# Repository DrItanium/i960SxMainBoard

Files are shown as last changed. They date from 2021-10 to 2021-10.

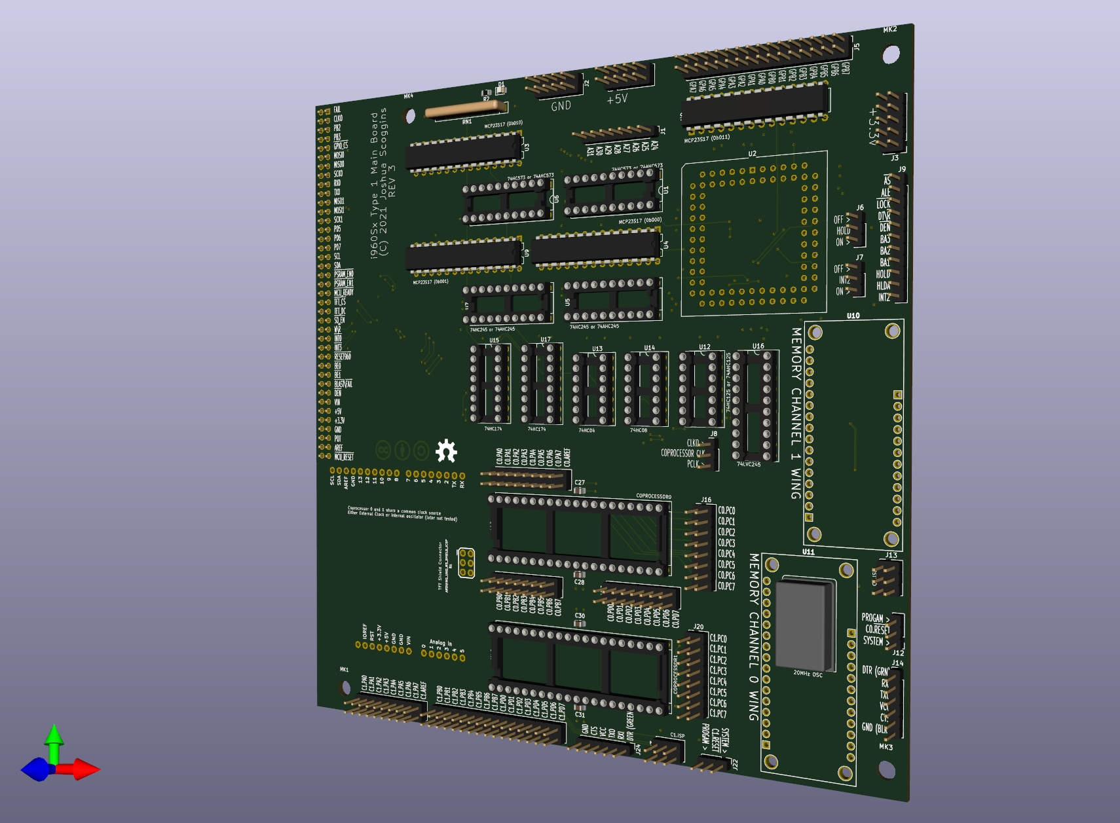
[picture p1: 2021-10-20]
images/i960BasicProcessorHardware_REV3_SIDE0.png

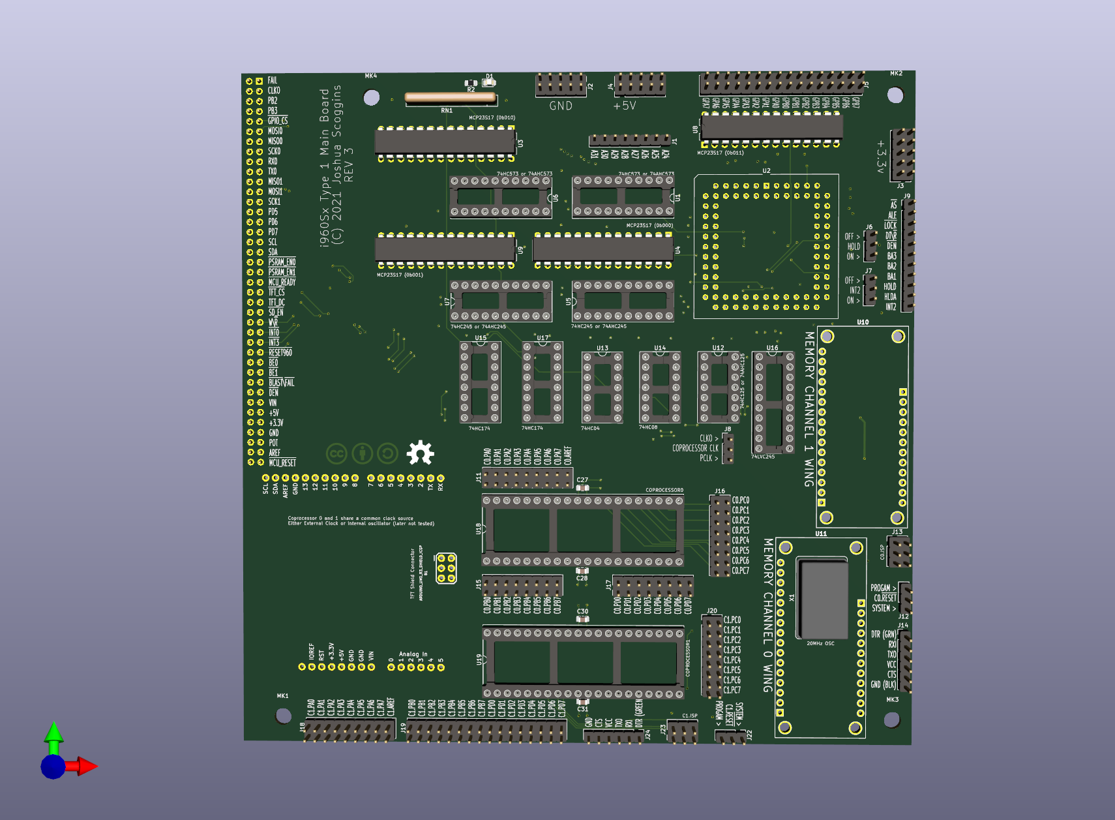
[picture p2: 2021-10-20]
images/i960BasicProcessorHardware_REV3_FRONT.png

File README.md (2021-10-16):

This is the kicad project for my basic i960Sx mainboard

This is the culmination of many different designs with the most prominent being
the flattening of my internal modular board design. It was made up of mega2560
shield form factors and nucleo-144 form factor boards. It allowed me to mix and
match ideas without having to fully lay everything out over and over again. I
have no plans of releasing those designs publically because they are not
useful to anyone but myself.

This is a mini-itx board that requires a separate MightyCore development board
to plug into. This board is the culmination of years of work and design. I am
nowhere done but this is the next phase of the design

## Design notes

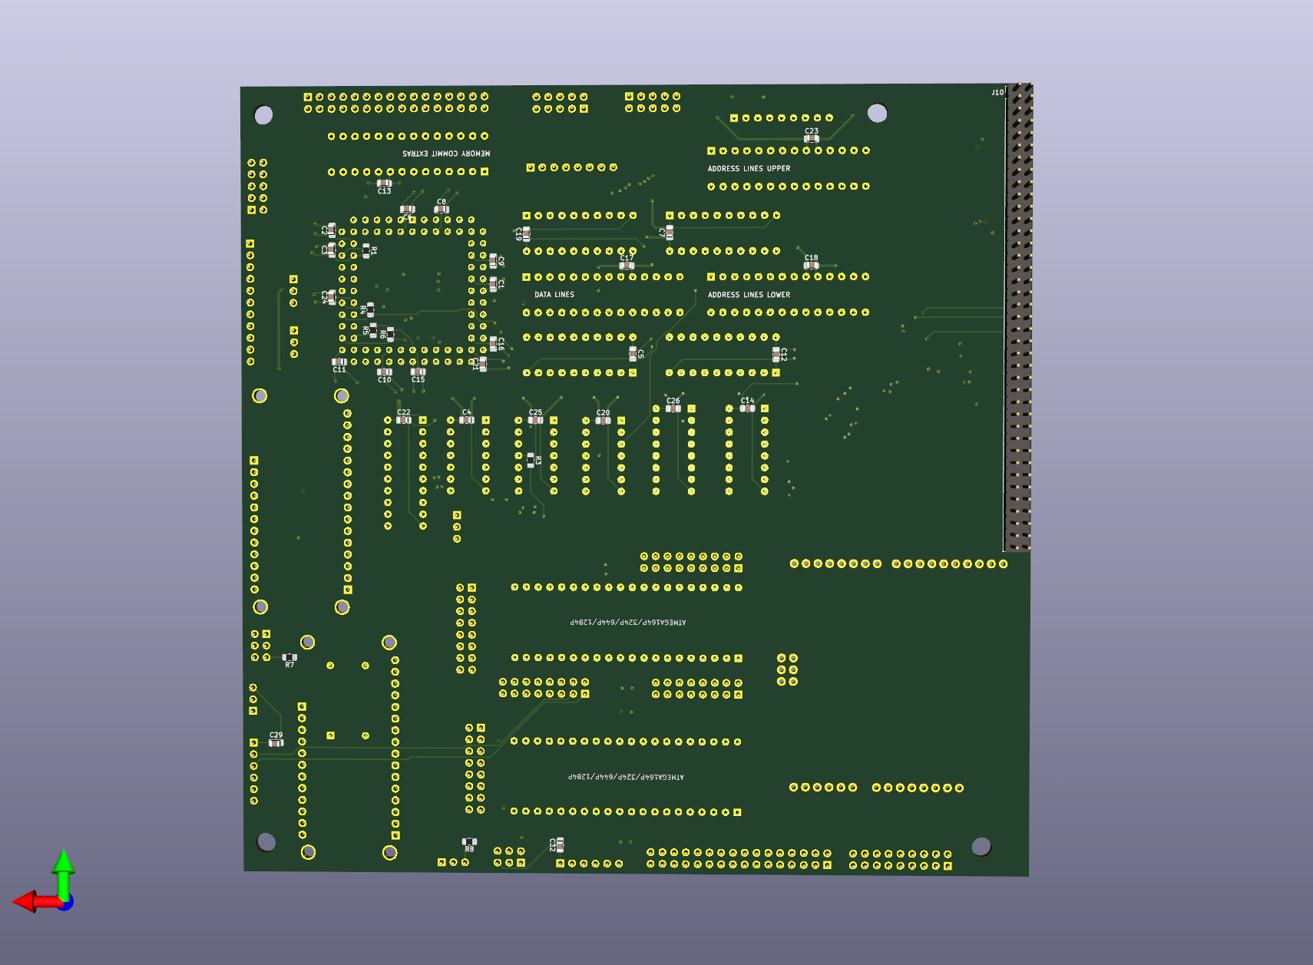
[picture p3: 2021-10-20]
images/i960BasicProcessorHardware_REV3_BACK.png

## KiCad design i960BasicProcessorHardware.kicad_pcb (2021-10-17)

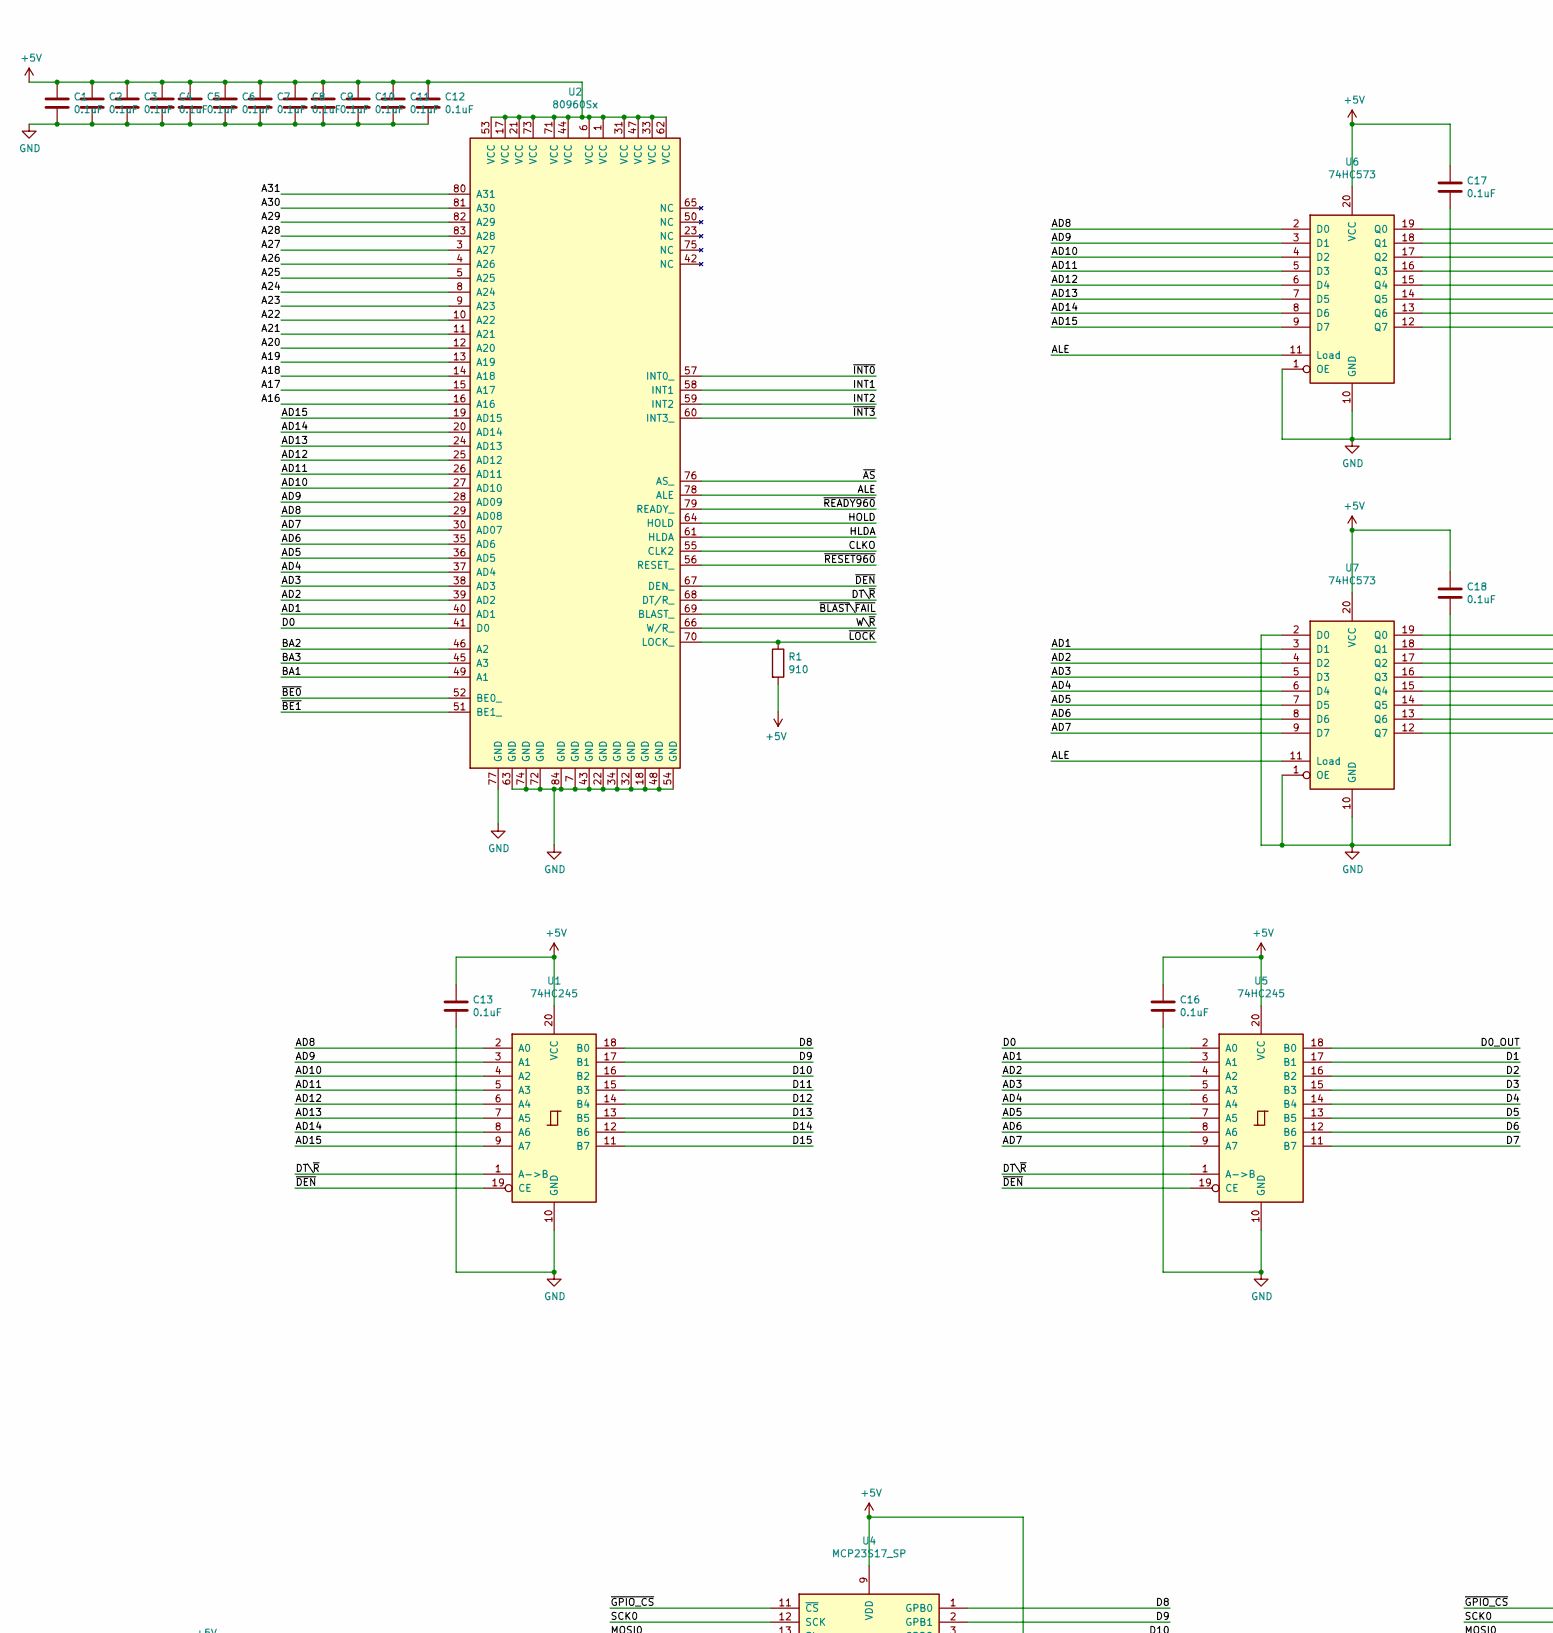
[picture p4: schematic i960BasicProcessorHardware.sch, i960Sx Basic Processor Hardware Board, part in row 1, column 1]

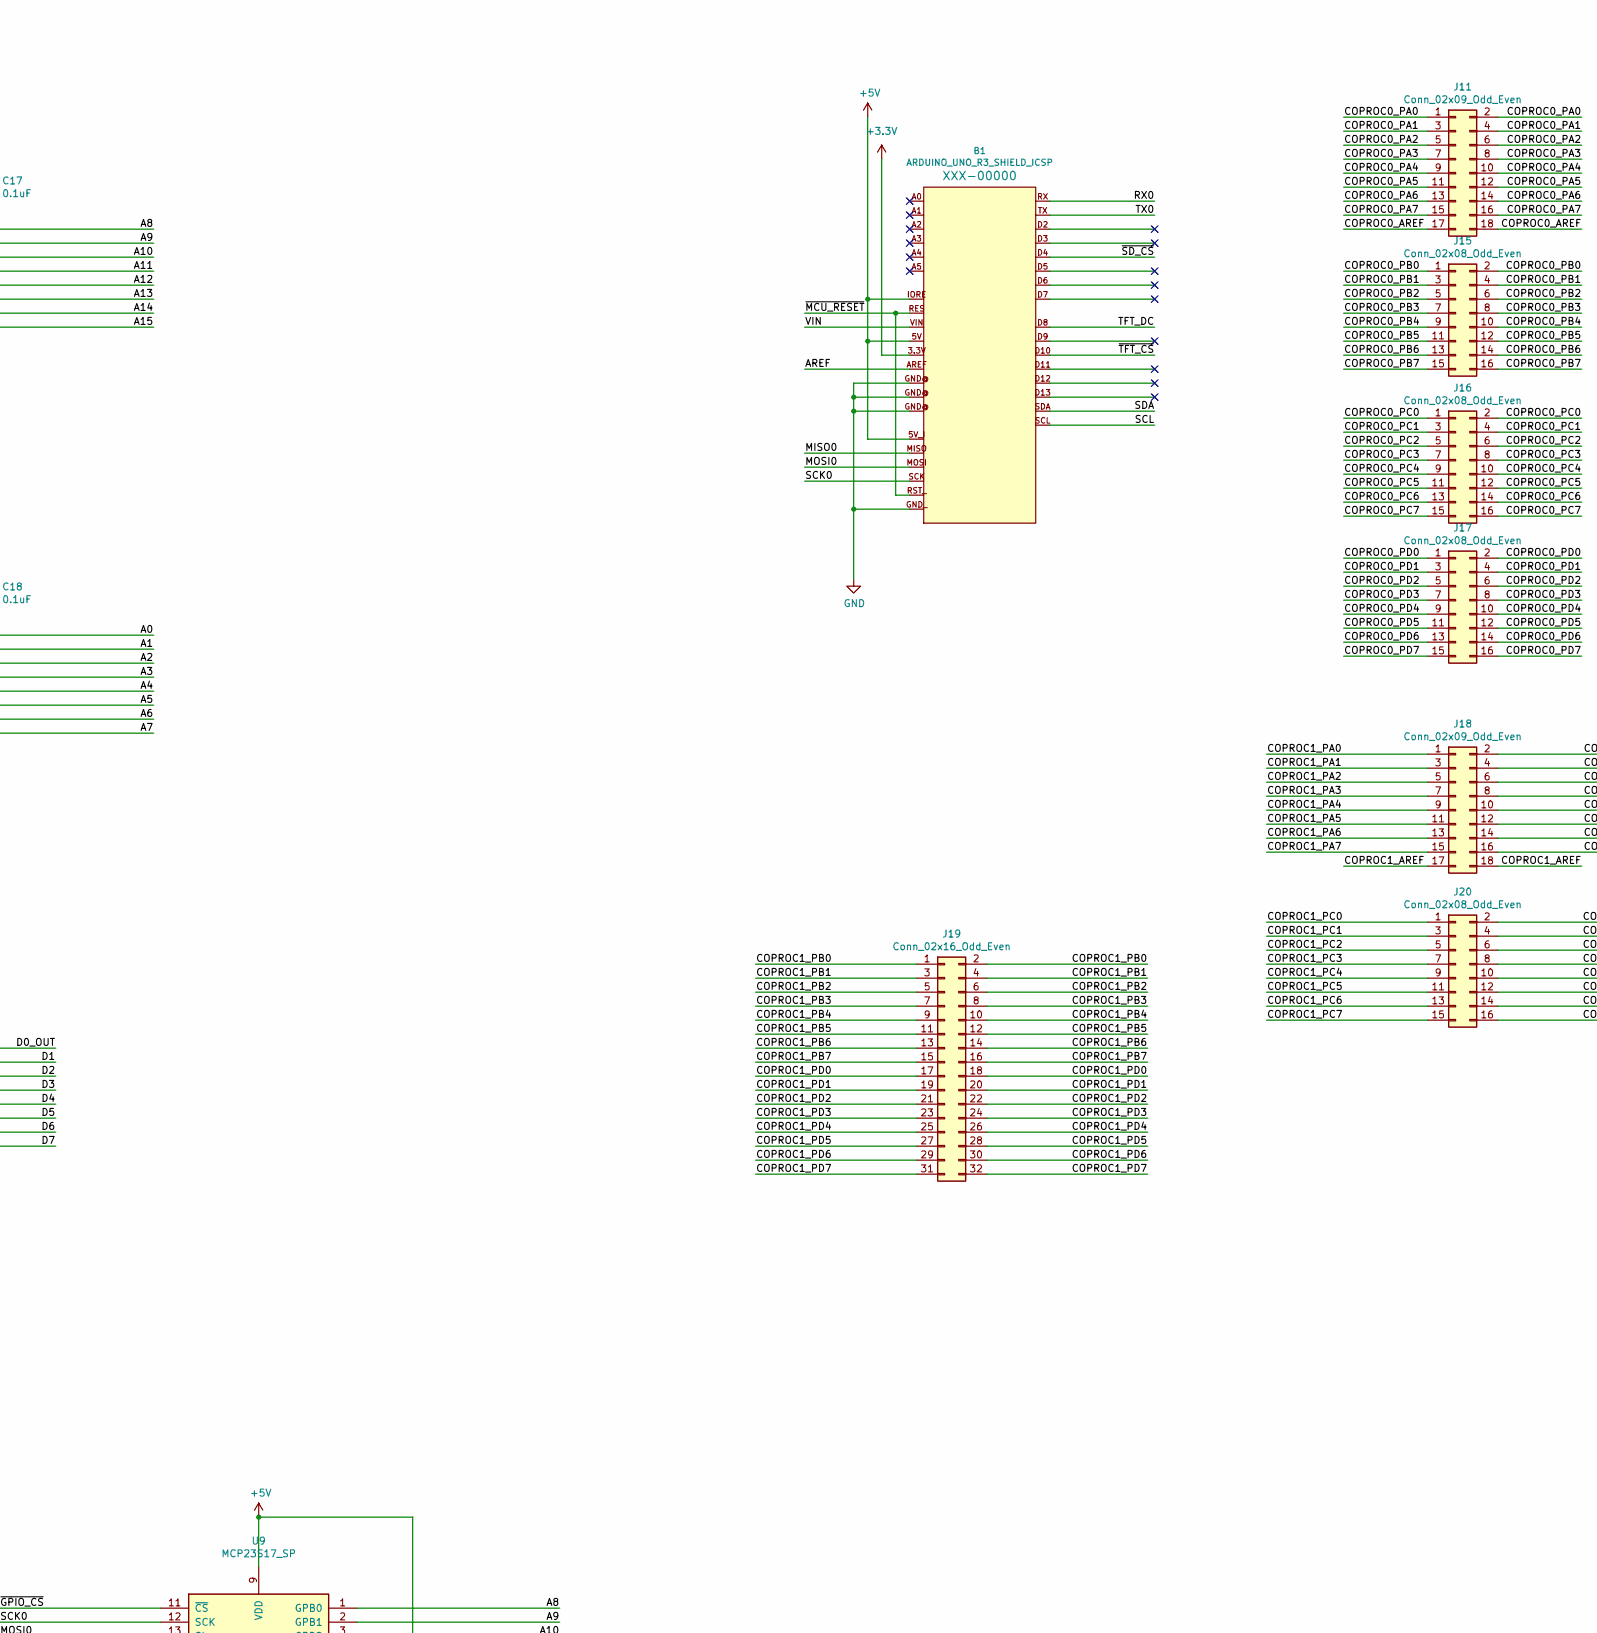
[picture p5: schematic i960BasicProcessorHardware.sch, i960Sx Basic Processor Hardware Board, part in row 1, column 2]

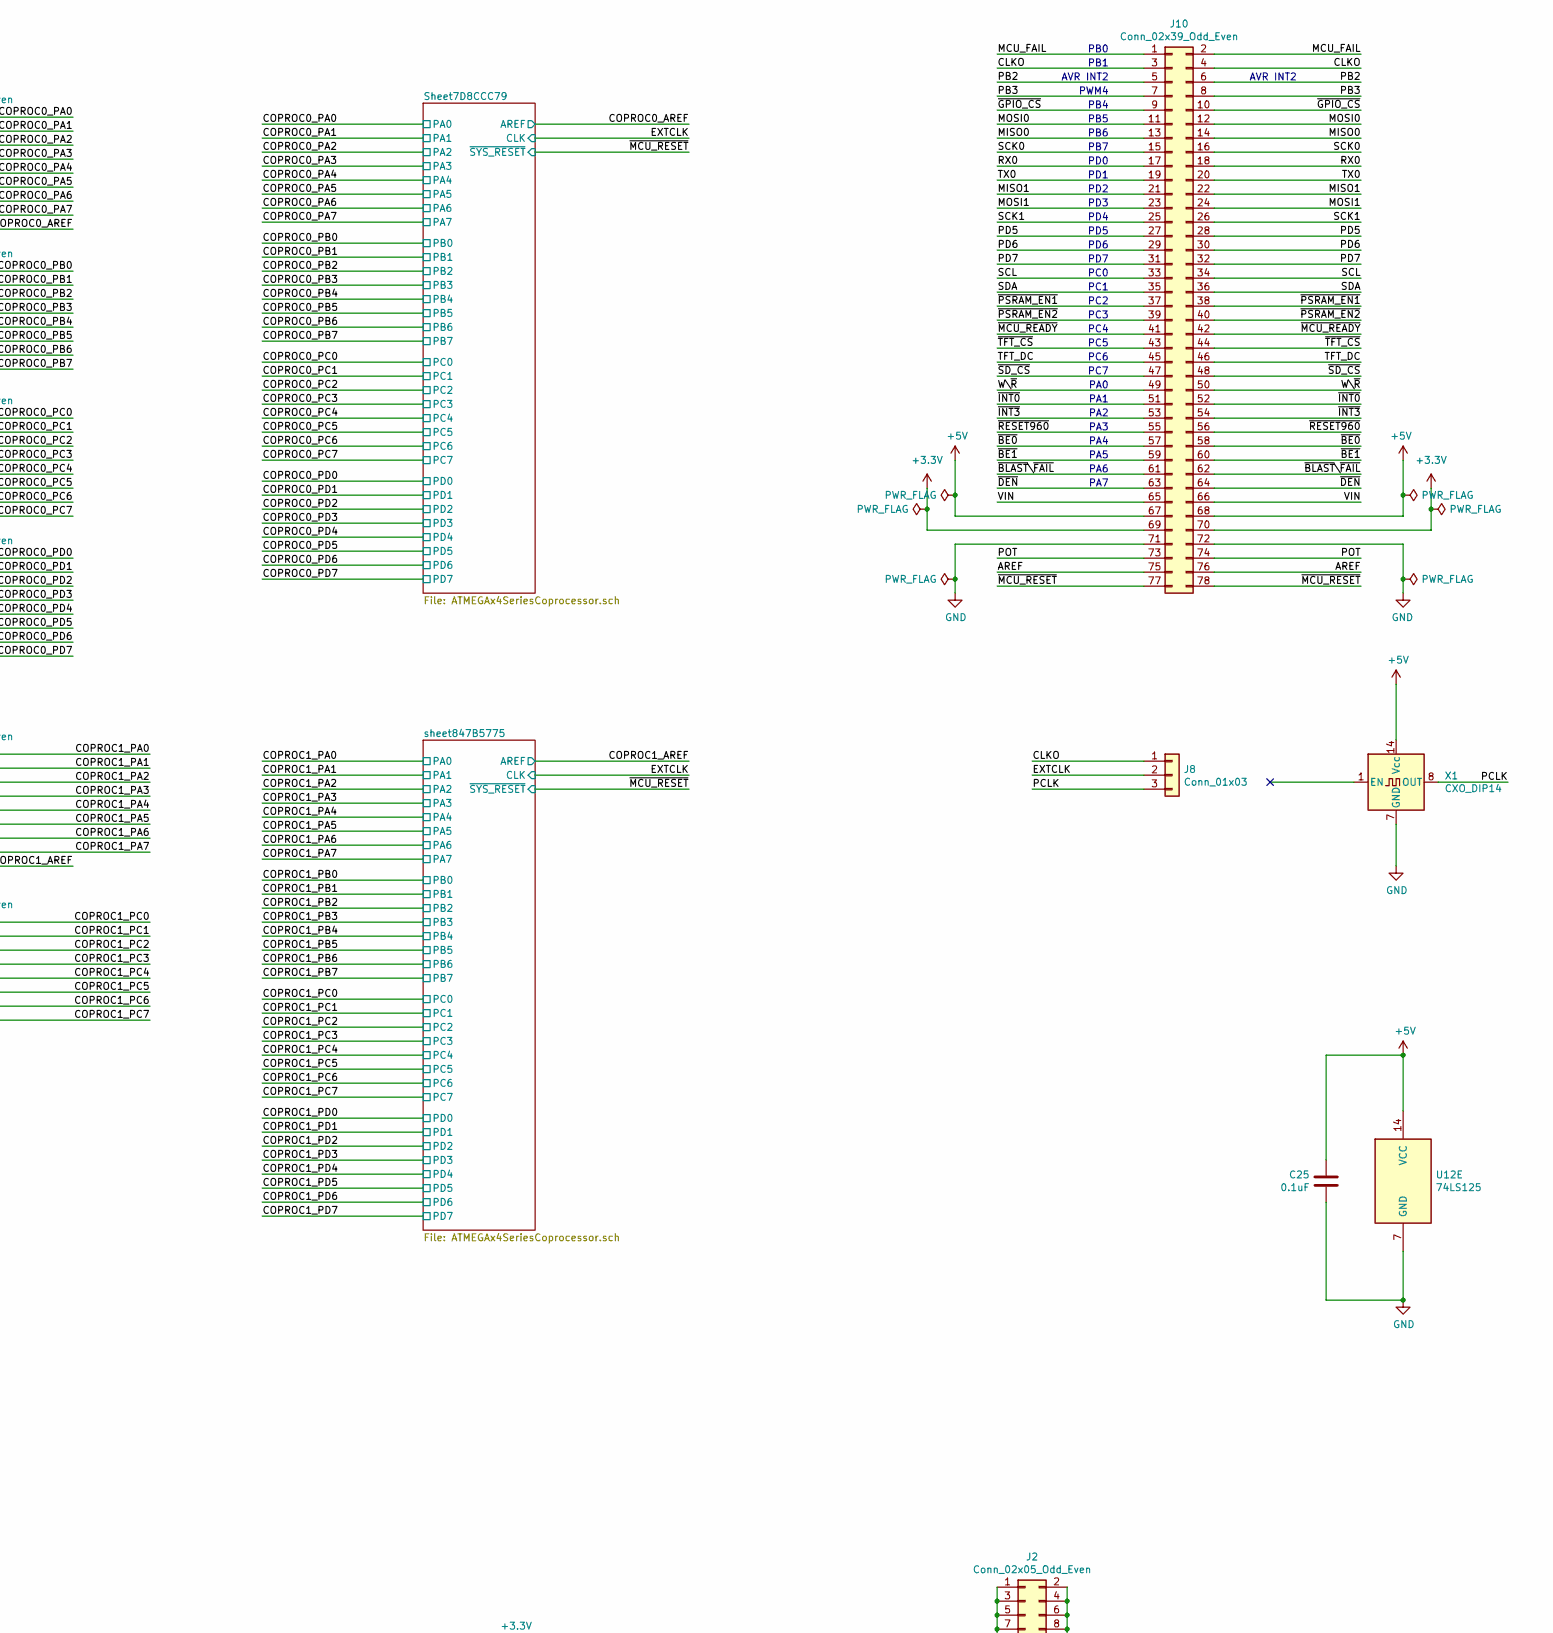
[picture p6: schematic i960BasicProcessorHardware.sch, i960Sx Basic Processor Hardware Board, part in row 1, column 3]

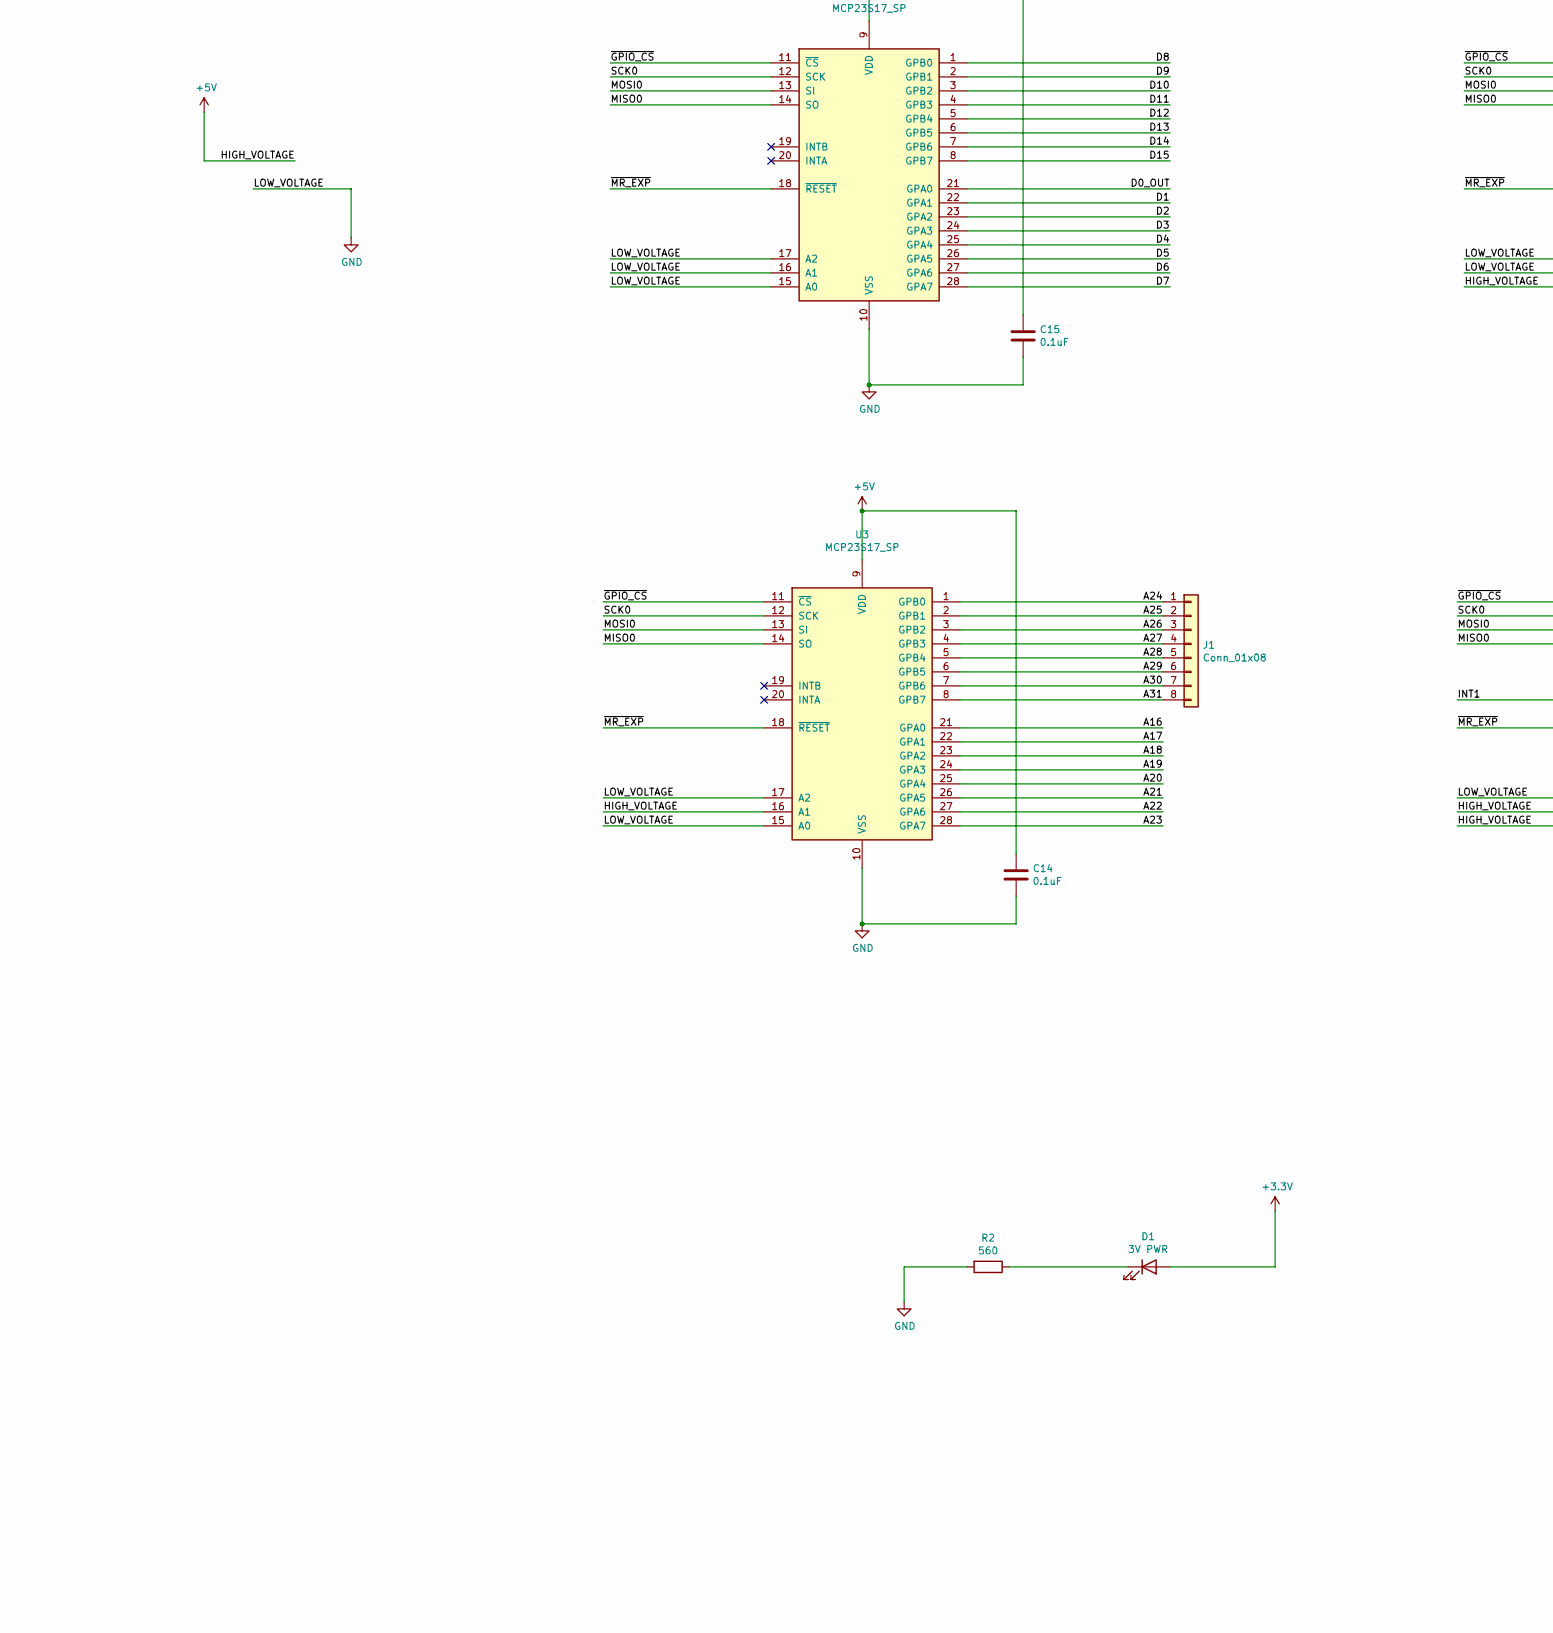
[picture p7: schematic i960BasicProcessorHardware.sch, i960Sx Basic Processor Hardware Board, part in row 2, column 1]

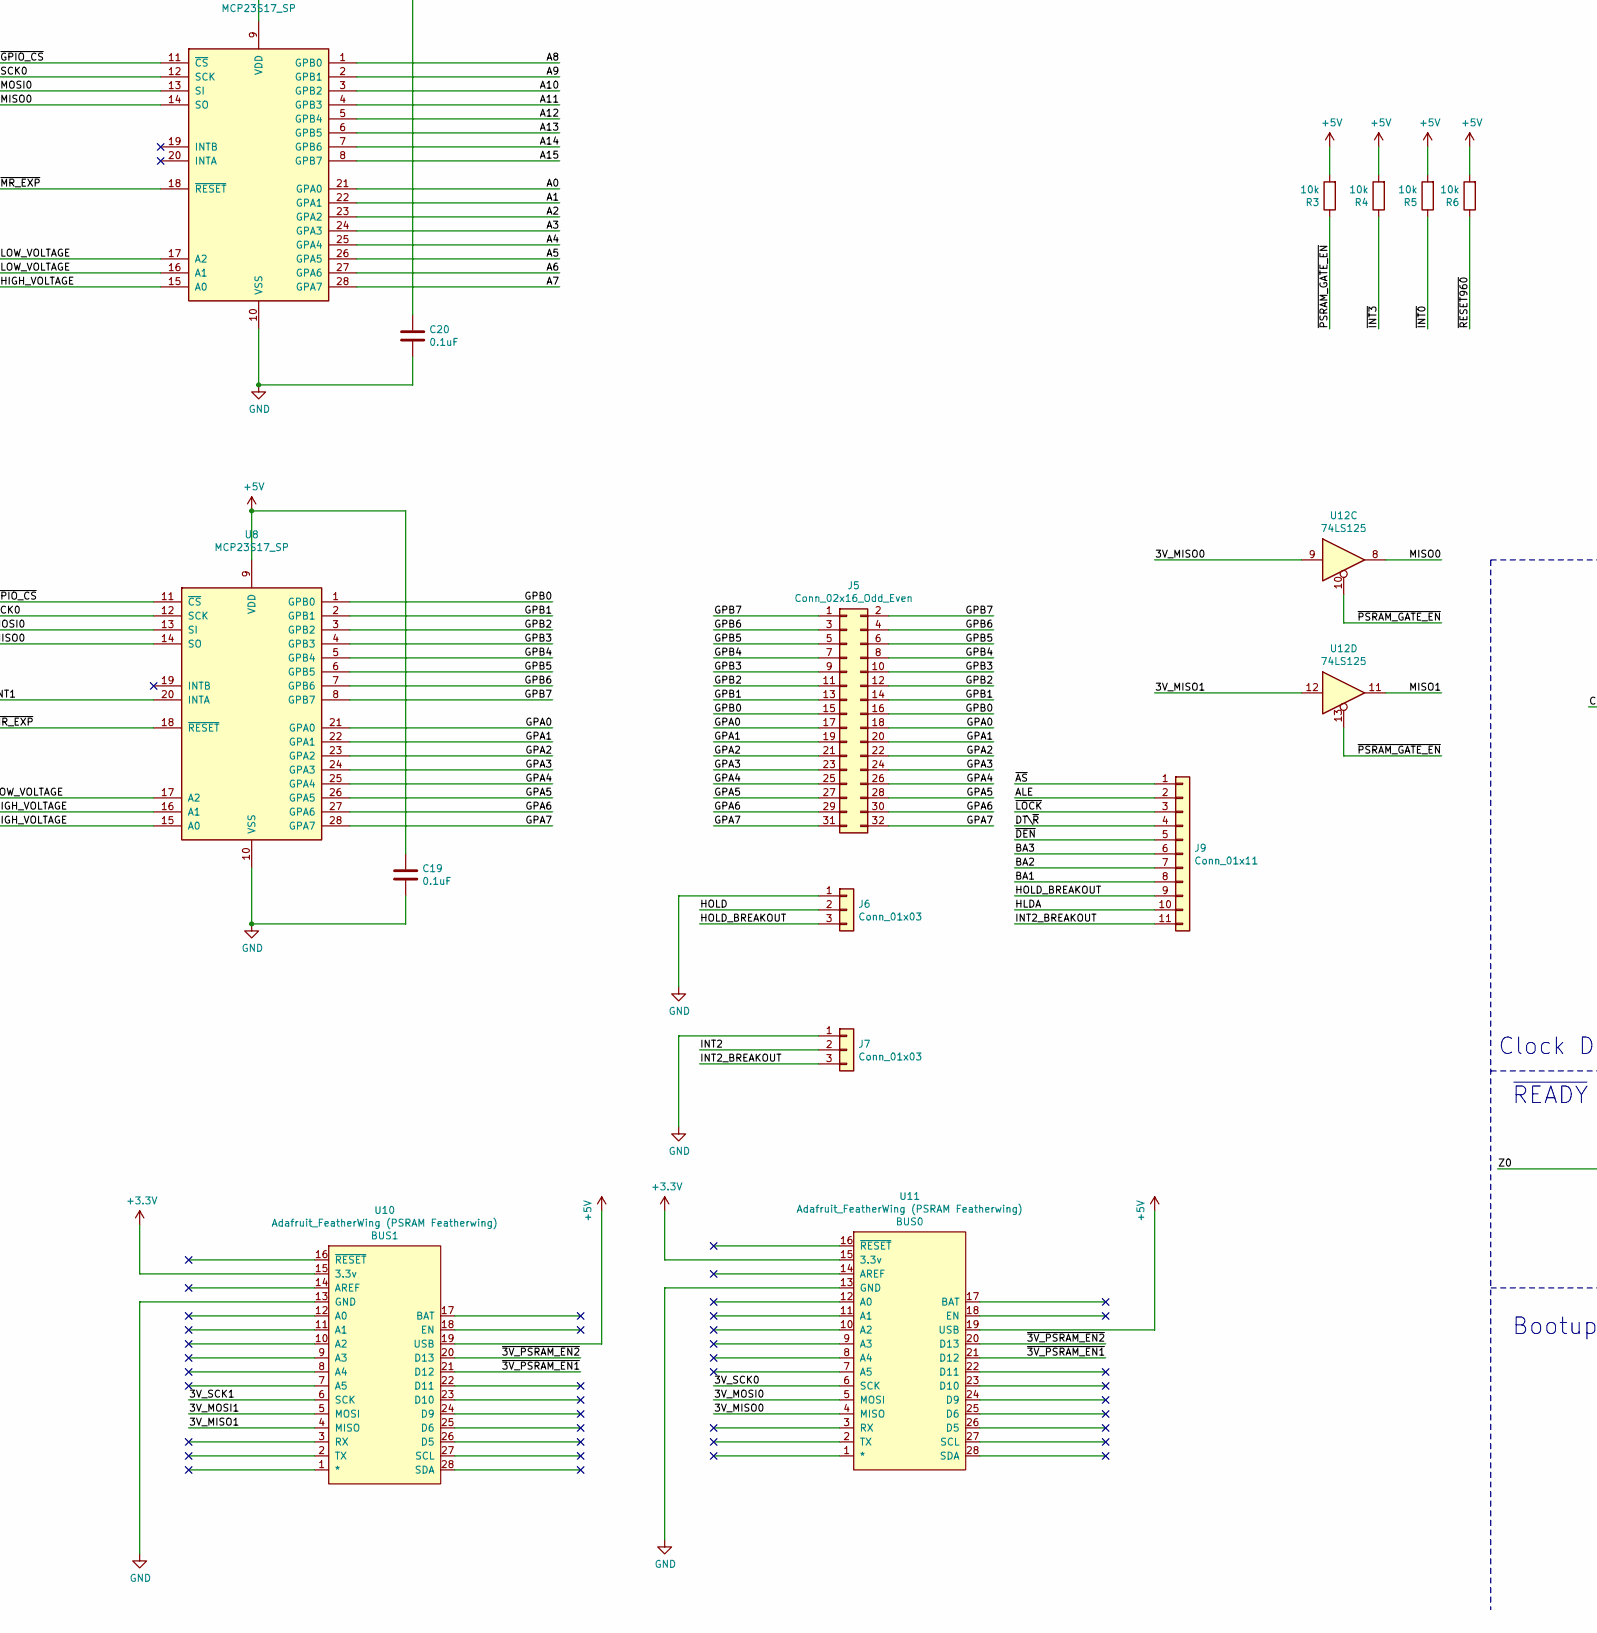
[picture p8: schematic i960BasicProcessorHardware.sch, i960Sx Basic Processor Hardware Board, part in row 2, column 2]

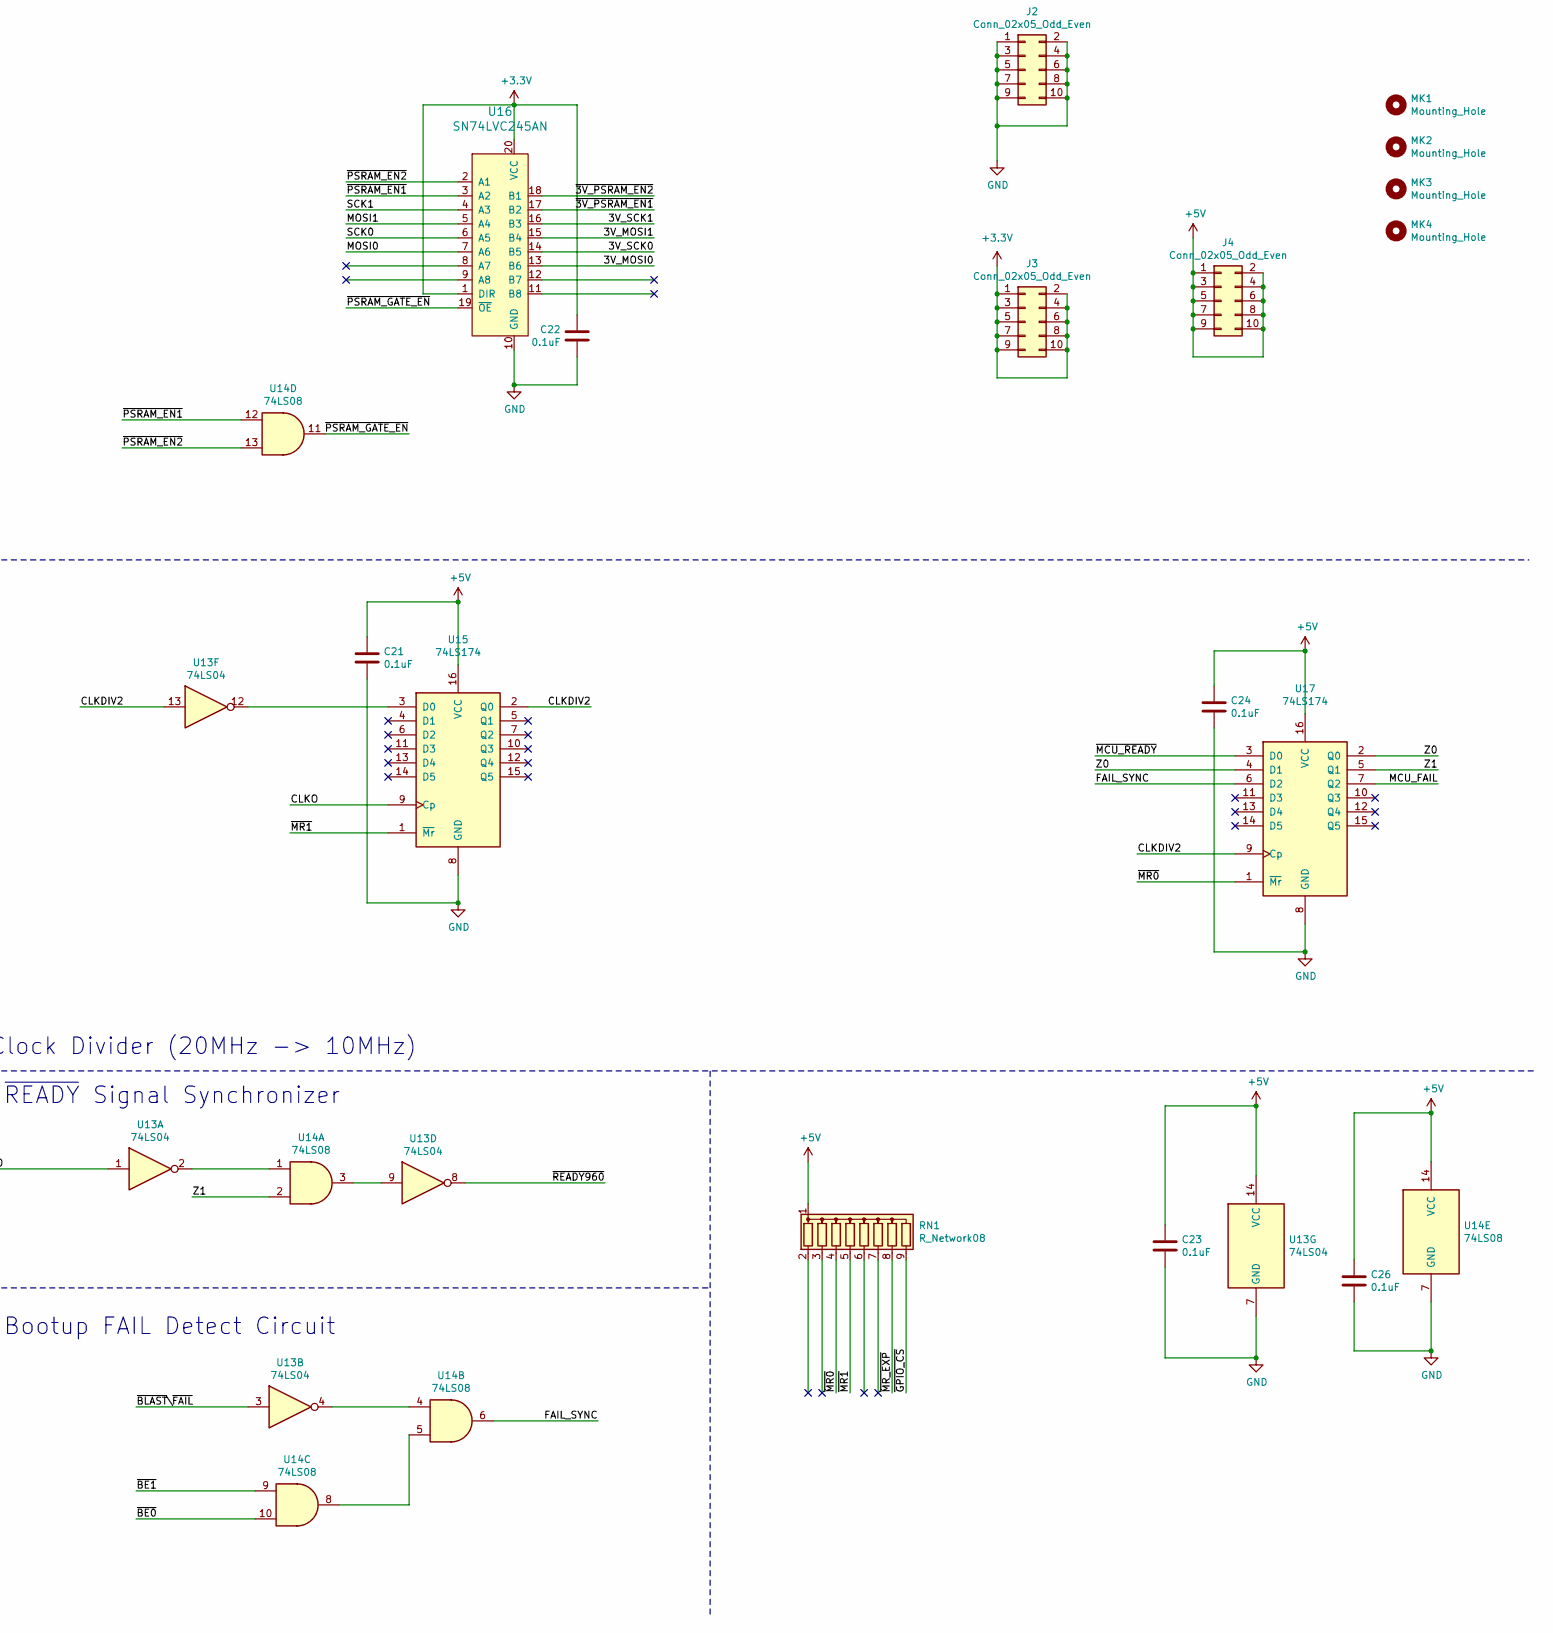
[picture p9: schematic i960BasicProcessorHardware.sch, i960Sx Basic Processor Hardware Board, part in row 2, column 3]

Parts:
B1: ARDUINO_UNO_R3_SHIELD_ICSP; UNO_R3_SHIELD_ICSP
C1, C2, C3, C4, C5, C6, C7, C8, C9, C10, C11, C12, C13, C14, C15, C16, C17, C18, C19, C20, C21, C22, C23, C24, C25, C26: 0.1uF; C_0805_2012Metric_Pad1.18x1.45mm_HandSolder
D1: 3V PWR; LED_0805_2012Metric_Pad1.15x1.40mm_HandSolder
J1: Conn_01x08; PinHeader_1x08_P2.54mm_Vertical
J2, J3, J4: Conn_02x05_Odd_Even; PinHeader_2x05_P2.54mm_Vertical
J5, J19: Conn_02x16_Odd_Even; PinHeader_2x16_P2.54mm_Vertical
J6, J7, J8: Conn_01x03; PinHeader_1x03_P2.54mm_Vertical
J9: Conn_01x11; PinHeader_1x11_P2.54mm_Vertical
J10: Conn_02x39_Odd_Even; PinHeader_2x39_P2.54mm_Vertical
J11, J18: Conn_02x09_Odd_Even; PinHeader_2x09_P2.54mm_Vertical
J15, J16, J17, J20: Conn_02x08_Odd_Even; PinHeader_2x08_P2.54mm_Vertical
MK1, MK2, MK3, MK4: Mounting_Hole; MountingHole_4.3mm_M4
R1: 910; R_0805_2012Metric_Pad1.20x1.40mm_HandSolder
R2: 560; R_0805_2012Metric_Pad1.20x1.40mm_HandSolder
R3, R4, R5, R6: 10k; R_0805_2012Metric_Pad1.20x1.40mm_HandSolder
RN1: R_Network08; R_Array_SIP9
U1, U5: 74HC245; DIP-20_W7.62mm_Socket
U2: 80960Sx; PLCC-84_THT-Socket
U3, U4, U8, U9: MCP23S17_SP; DIP-28_W7.62mm
U6, U7: 74HC573; DIP-20_W7.62mm_Socket
U10, U11: Adafruit_FeatherWing (PSRAM Featherwing); ADAFRUIT_FEATHER
U12: 74LS125; DIP-14_W7.62mm_Socket
U13: 74LS04; DIP-14_W7.62mm_Socket
U14: 74LS08; DIP-14_W7.62mm_Socket
U15, U17: 74LS174; DIP-16_W7.62mm_Socket
U16: SN74LVC245AN; DIP-20_W7.62mm_Socket; MPN SN74LVC245AN; Digi-Key_PN 296-8503-5-ND
X1: CXO_DIP14; Oscillator_DIP-14

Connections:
+3V3: B1.3.3V, C22.1, D1.2 (A), J3.1, J3.2, J3.3, J3.4, J3.5, J3.6, J3.7, J3.8, J3.9, J3.10, J10.69, J10.70, U10.15 (3.3v), U11.15 (3.3v), U16.1 (DIR), U16.20 (VCC)
+5V: B1.5V, B1.5V_I (VCC), B1.IORE (IOREF), C1.1, C2.1, C3.1, C4.1, C5.1, C6.1, C7.1, C8.1, C9.1, C10.1, C11.1, C12.1, C13.1, C14.1, C15.1, C16.1, C17.1, C18.1, C19.1, C20.1, C21.1, C23.1, C24.1, C25.1, C26.1, J4.1, J4.2, J4.3, J4.4, J4.5, J4.6, J4.7, J4.8, J4.9, J4.10, J10.67, J10.68, R1.2, R3.2, R4.2, R5.2, R6.2, RN1.1 (common), U1.20 (VCC), U2.1 (VCC), U2.6 (VCC), U2.17 (VCC), U2.21 (VCC), U2.31 (VCC), U2.33 (VCC), U2.44 (VCC), U2.47 (VCC), U2.53 (VCC), U2.62 (VCC), U2.71 (VCC), U2.73 (VCC), U3.9 (VDD), U3.16 (A1), U4.9 (VDD), U5.20 (VCC), U6.20 (VCC), U7.20 (VCC), U8.9 (VDD), U8.15 (A0), U8.16 (A1), U9.9 (VDD), U9.15 (A0), U10.19 (USB), U11.19 (USB), U12.14 (VCC), U13.14 (VCC), U14.14 (VCC), U15.16 (VCC), U17.16 (VCC), X1.14 (Vcc); also elsewhere on the board
/3V_MISO0: U11.4 (MISO), U12.9
/3V_MISO1: U10.4 (MISO), U12.12
/3V_MOSI0: U11.5 (MOSI), U16.13 (B6)
/3V_MOSI1: U10.5 (MOSI), U16.15 (B4)
/3V_SCK0: U11.6 (SCK), U16.14 (B5)
/3V_SCK1: U10.6 (SCK), U16.16 (B3)
/A0: U7.19 (Q0), U9.21 (GPA0)
/A1: U7.18 (Q1), U9.22 (GPA1)
/A2: U7.17 (Q2), U9.23 (GPA2)
/A3: U7.16 (Q3), U9.24 (GPA3)
/A4: U7.15 (Q4), U9.25 (GPA4)
/A5: U7.14 (Q5), U9.26 (GPA5)
/A6: U7.13 (Q6), U9.27 (GPA6)
/A7: U7.12 (Q7), U9.28 (GPA7)
/A8: U6.19 (Q0), U9.1 (GPB0)
/A9: U6.18 (Q1), U9.2 (GPB1)
/A10: U6.17 (Q2), U9.3 (GPB2)
/A11: U6.16 (Q3), U9.4 (GPB3)
/A12: U6.15 (Q4), U9.5 (GPB4)
/A13: U6.14 (Q5), U9.6 (GPB5)
/A14: U6.13 (Q6), U9.7 (GPB6)
/A15: U6.12 (Q7), U9.8 (GPB7)
/A16: U2.16 (A16), U3.21 (GPA0)
/A17: U2.15 (A17), U3.22 (GPA1)
/A18: U2.14 (A18), U3.23 (GPA2)
/A19: U2.13 (A19), U3.24 (GPA3)
/A20: U2.12 (A20), U3.25 (GPA4)
/A21: U2.11 (A21), U3.26 (GPA5)
/A22: U2.10 (A22), U3.27 (GPA6)
/A23: U2.9 (A23), U3.28 (GPA7)
/A24: J1.1, U2.8 (A24), U3.1 (GPB0)
/A25: J1.2, U2.5 (A25), U3.2 (GPB1)
/A26: J1.3, U2.4 (A26), U3.3 (GPB2)
/A27: J1.4, U2.3 (A27), U3.4 (GPB3)
/A28: J1.5, U2.83 (A28), U3.5 (GPB4)
/A29: J1.6, U2.82 (A29), U3.6 (GPB5)
/A30: J1.7, U2.81 (A30), U3.7 (GPB6)
/A31: J1.8, U2.80 (A31), U3.8 (GPB7)
/AD1: U2.40 (AD1), U5.3 (A1), U7.3 (D1)
/AD2: U2.39 (AD2), U5.4 (A2), U7.4 (D2)
/AD3: U2.38 (AD3), U5.5 (A3), U7.5 (D3)
/AD4: U2.37 (AD4), U5.6 (A4), U7.6 (D4)
/AD5: U2.36 (AD5), U5.7 (A5), U7.7 (D5)
/AD6: U2.35 (AD6), U5.8 (A6), U7.8 (D6)
/AD7: U2.30 (AD07), U5.9 (A7), U7.9 (D7)
/AD8: U1.2 (A0), U2.29 (AD08), U6.2 (D0)
/AD9: U1.3 (A1), U2.28 (AD09), U6.3 (D1)
/AD10: U1.4 (A2), U2.27 (AD10), U6.4 (D2)
/AD11: U1.5 (A3), U2.26 (AD11), U6.5 (D3)
/AD12: U1.6 (A4), U2.25 (AD12), U6.6 (D4)
/AD13: U1.7 (A5), U2.24 (AD13), U6.7 (D5)
/AD14: U1.8 (A6), U2.20 (AD14), U6.8 (D6)
/AD15: U1.9 (A7), U2.19 (AD15), U6.9 (D7)
/ALE: J9.2, U2.78 (ALE), U6.11 (Load), U7.11 (Load)
/AREF: B1.AREF, J10.75, J10.76
/BA1: J9.8, U2.49 (A1)
/BA2: J9.7, U2.46 (A2)
/BA3: J9.6, U2.45 (A3)
/CLKDIV2: U13.13, U15.2 (Q0), U17.9 (Cp)
/CLKO: J8.1, J10.3, J10.4, U2.55 (CLK2), U15.9 (Cp)
/COPROC0_AREF: J11.17, J11.18; also elsewhere on the board
/COPROC0_PA0: J11.1, J11.2; also elsewhere on the board
/COPROC0_PA1: J11.3, J11.4; also elsewhere on the board
/COPROC0_PA2: J11.5, J11.6; also elsewhere on the board
/COPROC0_PA3: J11.7, J11.8; also elsewhere on the board
/COPROC0_PA4: J11.9, J11.10; also elsewhere on the board
/COPROC0_PA5: J11.11, J11.12; also elsewhere on the board
/COPROC0_PA6: J11.13, J11.14; also elsewhere on the board
/COPROC0_PA7: J11.15, J11.16; also elsewhere on the board
/COPROC0_PB0: J15.1, J15.2; also elsewhere on the board
/COPROC0_PB1: J15.3, J15.4; also elsewhere on the board
/COPROC0_PB2: J15.5, J15.6; also elsewhere on the board
/COPROC0_PB3: J15.7, J15.8; also elsewhere on the board
/COPROC0_PB4: J15.9, J15.10; also elsewhere on the board
/COPROC0_PB5: J15.11, J15.12; also elsewhere on the board
/COPROC0_PB6: J15.13, J15.14; also elsewhere on the board
/COPROC0_PB7: J15.15, J15.16; also elsewhere on the board
/COPROC0_PC0: J16.1, J16.2; also elsewhere on the board
/COPROC0_PC1: J16.3, J16.4; also elsewhere on the board
/COPROC0_PC2: J16.5, J16.6; also elsewhere on the board
/COPROC0_PC3: J16.7, J16.8; also elsewhere on the board
/COPROC0_PC4: J16.9, J16.10; also elsewhere on the board
/COPROC0_PC5: J16.11, J16.12; also elsewhere on the board
/COPROC0_PC6: J16.13, J16.14; also elsewhere on the board
/COPROC0_PC7: J16.15, J16.16; also elsewhere on the board
/COPROC0_PD0: J17.1, J17.2; also elsewhere on the board
/COPROC0_PD1: J17.3, J17.4; also elsewhere on the board
/COPROC0_PD2: J17.5, J17.6; also elsewhere on the board
/COPROC0_PD3: J17.7, J17.8; also elsewhere on the board
/COPROC0_PD4: J17.9, J17.10; also elsewhere on the board
/COPROC0_PD5: J17.11, J17.12; also elsewhere on the board
/COPROC0_PD6: J17.13, J17.14; also elsewhere on the board
/COPROC0_PD7: J17.15, J17.16; also elsewhere on the board
/COPROC1_AREF: J18.17, J18.18; also elsewhere on the board
/COPROC1_PA0: J18.1, J18.2; also elsewhere on the board
/COPROC1_PA1: J18.3, J18.4; also elsewhere on the board
/COPROC1_PA2: J18.5, J18.6; also elsewhere on the board
/COPROC1_PA3: J18.7, J18.8; also elsewhere on the board
/COPROC1_PA4: J18.9, J18.10; also elsewhere on the board
/COPROC1_PA5: J18.11, J18.12; also elsewhere on the board
/COPROC1_PA6: J18.13, J18.14; also elsewhere on the board
/COPROC1_PA7: J18.15, J18.16; also elsewhere on the board
/COPROC1_PB0: J19.1, J19.2; also elsewhere on the board
/COPROC1_PB1: J19.3, J19.4; also elsewhere on the board
/COPROC1_PB2: J19.5, J19.6; also elsewhere on the board
/COPROC1_PB3: J19.7, J19.8; also elsewhere on the board
/COPROC1_PB4: J19.9, J19.10; also elsewhere on the board
/COPROC1_PB5: J19.11, J19.12; also elsewhere on the board
/COPROC1_PB6: J19.13, J19.14; also elsewhere on the board
/COPROC1_PB7: J19.15, J19.16; also elsewhere on the board
/COPROC1_PC0: J20.1, J20.2; also elsewhere on the board
/COPROC1_PC1: J20.3, J20.4; also elsewhere on the board
/COPROC1_PC2: J20.5, J20.6; also elsewhere on the board
/COPROC1_PC3: J20.7, J20.8; also elsewhere on the board
/COPROC1_PC4: J20.9, J20.10; also elsewhere on the board
/COPROC1_PC5: J20.11, J20.12; also elsewhere on the board
/COPROC1_PC6: J20.13, J20.14; also elsewhere on the board
/COPROC1_PC7: J20.15, J20.16; also elsewhere on the board
/COPROC1_PD0: J19.17, J19.18; also elsewhere on the board
/COPROC1_PD1: J19.19, J19.20; also elsewhere on the board
/COPROC1_PD2: J19.21, J19.22; also elsewhere on the board
/COPROC1_PD3: J19.23, J19.24; also elsewhere on the board
/COPROC1_PD4: J19.25, J19.26; also elsewhere on the board
/COPROC1_PD5: J19.27, J19.28; also elsewhere on the board
/COPROC1_PD6: J19.29, J19.30; also elsewhere on the board
/COPROC1_PD7: J19.31, J19.32; also elsewhere on the board
/D0: U2.41 (D0), U5.2 (A0)
/D0_OUT: U4.21 (GPA0), U5.18 (B0)
/D1: U4.22 (GPA1), U5.17 (B1)
/D2: U4.23 (GPA2), U5.16 (B2)
/D3: U4.24 (GPA3), U5.15 (B3)
/D4: U4.25 (GPA4), U5.14 (B4)
/D5: U4.26 (GPA5), U5.13 (B5)
/D6: U4.27 (GPA6), U5.12 (B6)
/D7: U4.28 (GPA7), U5.11 (B7)
/D8: U1.18 (B0), U4.1 (GPB0)
/D9: U1.17 (B1), U4.2 (GPB1)
/D10: U1.16 (B2), U4.3 (GPB2)
/D11: U1.15 (B3), U4.4 (GPB3)
/D12: U1.14 (B4), U4.5 (GPB4)
/D13: U1.13 (B5), U4.6 (GPB5)
/D14: U1.12 (B6), U4.7 (GPB6)
/D15: U1.11 (B7), U4.8 (GPB7)
/DT\~R: J9.4, U1.1 (A->B), U2.68 (DT/R_), U5.1 (A->B)
/EXTCLK: J8.2; also elsewhere on the board
/FAIL_SYNC: U14.6, U17.6 (D2)
/GPA0: J5.17, J5.18, U8.21 (GPA0)
/GPA1: J5.19, J5.20, U8.22 (GPA1)
/GPA2: J5.21, J5.22, U8.23 (GPA2)
/GPA3: J5.23, J5.24, U8.24 (GPA3)
/GPA4: J5.25, J5.26, U8.25 (GPA4)
/GPA5: J5.27, J5.28, U8.26 (GPA5)
/GPA6: J5.29, J5.30, U8.27 (GPA6)
/GPA7: J5.31, J5.32, U8.28 (GPA7)
/GPB0: J5.15, J5.16, U8.1 (GPB0)
/GPB1: J5.13, J5.14, U8.2 (GPB1)
/GPB2: J5.11, J5.12, U8.3 (GPB2)
/GPB3: J5.9, J5.10, U8.4 (GPB3)
/GPB4: J5.7, J5.8, U8.5 (GPB4)
/GPB5: J5.5, J5.6, U8.6 (GPB5)
/GPB6: J5.3, J5.4, U8.7 (GPB6)
/GPB7: J5.1, J5.2, U8.8 (GPB7)
/HLDA: J9.10, U2.61 (HLDA)
/HOLD: J6.2, U2.64 (HOLD)
/HOLD_BREAKOUT: J6.3, J9.9
/INT1: U2.58 (INT1), U8.20 (INTA)
/INT2: J7.2, U2.59 (INT2)
/INT2_BREAKOUT: J7.3, J9.11
/MCU_FAIL: J10.1, J10.2, U17.7 (Q2)
/MISO0: B1.MISO, J10.13, J10.14, U3.14 (SO), U4.14 (SO), U8.14 (SO), U9.14 (SO), U12.8
/MISO1: J10.21, J10.22, U12.11
/MOSI0: B1.MOSI, J10.11, J10.12, U3.13 (SI), U4.13 (SI), U8.13 (SI), U9.13 (SI), U16.7 (A6)
/MOSI1: J10.23, J10.24, U16.5 (A4)
/PB2: J10.5, J10.6
/PB3: J10.7, J10.8
/PCLK: J8.3, X1.8 (OUT)
/PD5: J10.27, J10.28
/PD6: J10.29, J10.30
/PD7: J10.31, J10.32
/POT: J10.73, J10.74
/RX0: B1.RX (D0), J10.17, J10.18
/SCK0: B1.SCK, J10.15, J10.16, U3.12 (SCK), U4.12 (SCK), U8.12 (SCK), U9.12 (SCK), U16.6 (A5)
/SCK1: J10.25, J10.26, U16.4 (A3)
/SCL: B1.SCL, J10.33, J10.34
/SDA: B1.SDA, J10.35, J10.36
/TFT_DC: B1.D8, J10.45, J10.46
/TX0: B1.TX (D1), J10.19, J10.20
/VIN: B1.VIN, J10.65, J10.66
/W\~R~: J10.49, J10.50, U2.66 (W/R_)
/Z0: U13.1, U17.2 (Q0), U17.4 (D1)
/Z1: U14.2, U17.5 (Q1)
/~3V_PSRAM_EN1: U10.21 (D12), U11.21 (D12), U16.17 (B2)
/~3V_PSRAM_EN2: U10.20 (D13), U11.20 (D13), U16.18 (B1)
/~AS: J9.1, U2.76 (AS_)
/~BE0: J10.57, J10.58, U2.52 (BE0_), U14.10
/~BE1: J10.59, J10.60, U2.51 (BE1_), U14.9
/~BLAST~\~FAIL~: J10.61, J10.62, U2.69 (BLAST_), U13.3
/~DEN: J9.5, J10.63, J10.64, U1.19 (CE), U2.67 (DEN_), U5.19 (CE)
/~GPIO_CS: J10.9, J10.10, RN1.9 (R8), U3.11 (~CS~), U4.11 (~CS~), U8.11 (~CS~), U9.11 (~CS~)
/~INT0: J10.51, J10.52, R5.1, U2.57 (INT0_)
/~INT3: J10.53, J10.54, R4.1, U2.60 (INT3_)
/~LOCK: J9.3, R1.1, U2.70 (LOCK_)
/~MCU_READY: J10.41, J10.42, U17.3 (D0)
/~MCU_RESET: B1.RES (~RESET~), B1.RST_ (~RESET~), J10.77, J10.78; also elsewhere on the board
/~MR0: RN1.4 (R3), U17.1 (~Mr)
/~MR1: RN1.5 (R4), U15.1 (~Mr)
/~MR_EXP: RN1.8 (R7), U3.18 (~RESET~), U4.18 (~RESET~), U8.18 (~RESET~), U9.18 (~RESET~)
/~PSRAM_EN1: J10.37, J10.38, U14.12, U16.3 (A2)
/~PSRAM_EN2: J10.39, J10.40, U14.13, U16.2 (A1)
/~PSRAM_GATE_EN: R3.1, U12.10, U12.13, U14.11, U16.19 (~OE)
/~READY960: U2.79 (READY_), U13.8
/~RESET960: J10.55, J10.56, R6.1, U2.56 (RESET_)
/~SD_CS: B1.D4, J10.47, J10.48
/~TFT_CS: B1.D10 (*D10), J10.43, J10.44
GND: B1.GND@ (GND), B1.GND_ (GND), C1.2, C2.2, C3.2, C4.2, C5.2, C6.2, C7.2, C8.2, C9.2, C10.2, C11.2, C12.2, C13.2, C14.2, C15.2, C16.2, C17.2, C18.2, C19.2, C20.2, C21.2, C22.2, C23.2, C24.2, C25.2, C26.2, J2.1, J2.2, J2.3, J2.4, J2.5, J2.6, J2.7, J2.8, J2.9, J2.10, J6.1, J7.1, J10.71, J10.72, R2.2, U1.10 (GND), U2.7 (GND), U2.18 (GND), U2.22 (GND), U2.32 (GND), U2.34 (GND), U2.43 (GND), U2.48 (GND), U2.54 (GND), U2.63 (GND), U2.72 (GND), U2.74 (GND), U2.77 (GND), U2.84 (GND), U3.10 (VSS), U3.15 (A0), U3.17 (A2), U4.10 (VSS), U4.15 (A0), U4.16 (A1), U4.17 (A2), U5.10 (GND), U6.1 (OE), U6.10 (GND), U7.1 (OE), U7.2 (D0), U7.10 (GND), U8.10 (VSS), U8.17 (A2), U9.10 (VSS), U9.16 (A1), U9.17 (A2), U10.13 (GND), U11.13 (GND), U12.7 (GND), U13.7 (GND), U14.7 (GND), U15.8 (GND), U16.10 (GND), U17.8 (GND), X1.7 (GND); also elsewhere on the board
unnamed: D1.1 (K), R2.1
unnamed: U13.2, U14.1
unnamed: U13.4, U14.4
unnamed: U13.9, U14.3
unnamed: U13.12, U15.3 (D0)
unnamed: U14.5, U14.8

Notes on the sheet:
Bootup FAIL Detect Circuit
Clock Divider (20MHz -> 10MHz)
~READY~ Signal Synchronizer
PB0
PB1
PWM4
PB4
PB5
PB6
PB7
PD0
PD1
PD2
PD3
PD4
PD5
PD6
PD7
PC0
PC1
PC2
PC3
PC4
PC5
PC6
PC7
PA0
PA1
PA2
PA3
PA4
PA5
PA6
PA7
AVR INT2

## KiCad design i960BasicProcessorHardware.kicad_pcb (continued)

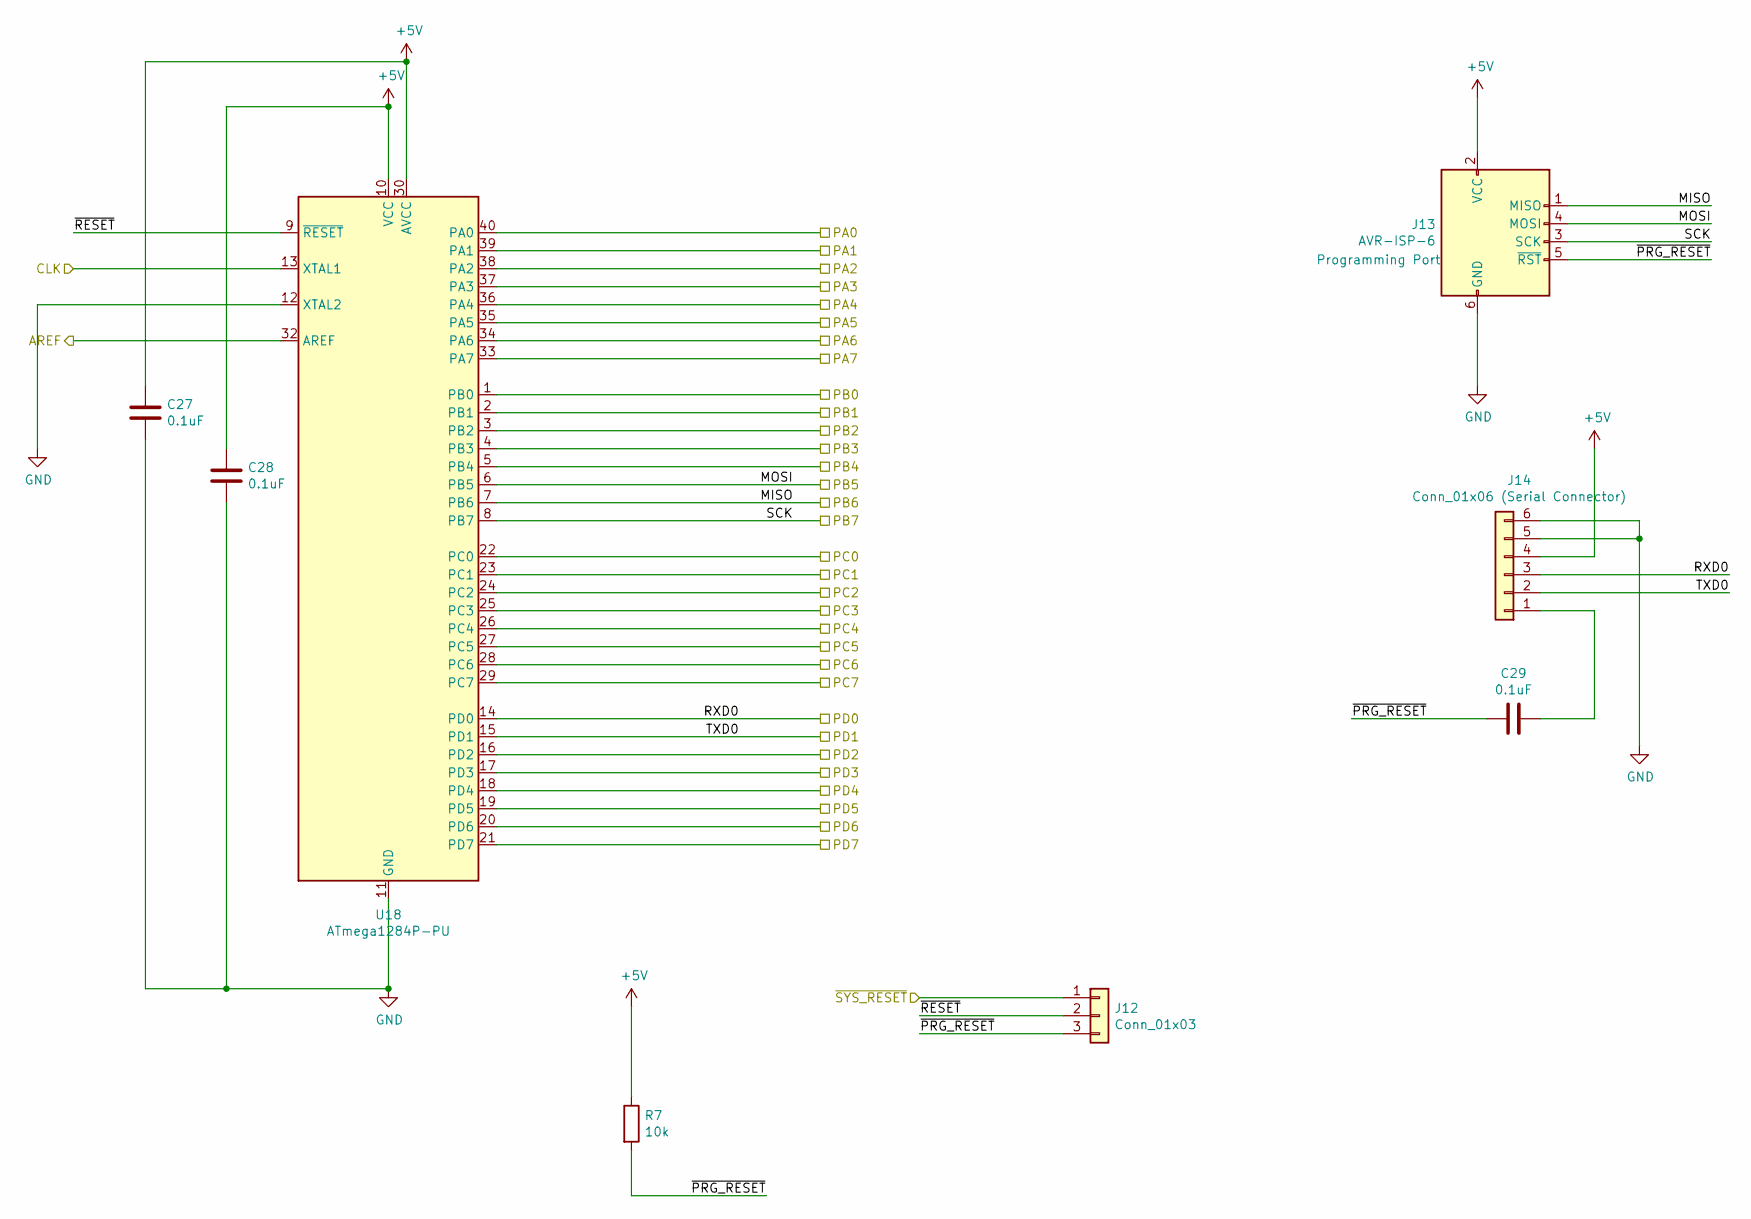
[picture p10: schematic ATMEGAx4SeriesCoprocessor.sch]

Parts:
C27, C28, C29: 0.1uF; C_0805_2012Metric_Pad1.18x1.45mm_HandSolder
J12: Conn_01x03; PinHeader_1x03_P2.54mm_Vertical
J13: AVR-ISP-6; PinHeader_2x03_P2.54mm_Vertical
J14: Conn_01x06 (Serial Connector); PinHeader_1x06_P2.54mm_Vertical
R7: 10k; R_0805_2012Metric_Pad1.20x1.40mm_HandSolder
U18: ATmega1284P-PU; DIP-40_W15.24mm_Socket

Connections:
+5V: C27.1, C28.1, J13.2 (VCC), J14.4, R7.1, U18.10 (VCC), U18.30 (AVCC); also elsewhere on the board
/COPROC0_AREF: U18.32 (AREF); also elsewhere on the board
/COPROC0_PA0: U18.40 (PA0); also elsewhere on the board
/COPROC0_PA1: U18.39 (PA1); also elsewhere on the board
/COPROC0_PA2: U18.38 (PA2); also elsewhere on the board
/COPROC0_PA3: U18.37 (PA3); also elsewhere on the board
/COPROC0_PA4: U18.36 (PA4); also elsewhere on the board
/COPROC0_PA5: U18.35 (PA5); also elsewhere on the board
/COPROC0_PA6: U18.34 (PA6); also elsewhere on the board
/COPROC0_PA7: U18.33 (PA7); also elsewhere on the board
/COPROC0_PB0: U18.1 (PB0); also elsewhere on the board
/COPROC0_PB1: U18.2 (PB1); also elsewhere on the board
/COPROC0_PB2: U18.3 (PB2); also elsewhere on the board
/COPROC0_PB3: U18.4 (PB3); also elsewhere on the board
/COPROC0_PB4: U18.5 (PB4); also elsewhere on the board
/COPROC0_PB5: J13.4 (MOSI), U18.6 (PB5); also elsewhere on the board
/COPROC0_PB6: J13.1 (MISO), U18.7 (PB6); also elsewhere on the board
/COPROC0_PB7: J13.3 (SCK), U18.8 (PB7); also elsewhere on the board
/COPROC0_PC0: U18.22 (PC0); also elsewhere on the board
/COPROC0_PC1: U18.23 (PC1); also elsewhere on the board
/COPROC0_PC2: U18.24 (PC2); also elsewhere on the board
/COPROC0_PC3: U18.25 (PC3); also elsewhere on the board
/COPROC0_PC4: U18.26 (PC4); also elsewhere on the board
/COPROC0_PC5: U18.27 (PC5); also elsewhere on the board
/COPROC0_PC6: U18.28 (PC6); also elsewhere on the board
/COPROC0_PC7: U18.29 (PC7); also elsewhere on the board
/COPROC0_PD0: J14.3, U18.14 (PD0); also elsewhere on the board
/COPROC0_PD1: J14.2, U18.15 (PD1); also elsewhere on the board
/COPROC0_PD2: U18.16 (PD2); also elsewhere on the board
/COPROC0_PD3: U18.17 (PD3); also elsewhere on the board
/COPROC0_PD4: U18.18 (PD4); also elsewhere on the board
/COPROC0_PD5: U18.19 (PD5); also elsewhere on the board
/COPROC0_PD6: U18.20 (PD6); also elsewhere on the board
/COPROC0_PD7: U18.21 (PD7); also elsewhere on the board
/EXTCLK: U18.13 (XTAL1); also elsewhere on the board
/Sheet7D8CCC79/~PRG_RESET: C29.2, J12.3, J13.5 (~RST), R7.2
/Sheet7D8CCC79/~RESET: J12.2, U18.9 (~RESET)
/~MCU_RESET: J12.1; also elsewhere on the board
GND: C27.2, C28.2, J13.6 (GND), J14.5, J14.6, U18.11 (GND), U18.12 (XTAL2), U18.31 (GND); also elsewhere on the board
unnamed: C29.1, J14.1

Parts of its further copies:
C30, C31, C32: 0.1uF; C_0805_2012Metric_Pad1.18x1.45mm_HandSolder
J22: Conn_01x03; PinHeader_1x03_P2.54mm_Vertical
J23: AVR-ISP-6; PinHeader_2x03_P2.54mm_Vertical
J24: Conn_01x06 (Serial Connector); PinHeader_1x06_P2.54mm_Vertical
R8: 10k; R_0805_2012Metric_Pad1.20x1.40mm_HandSolder
U19: ATmega1284P-PU; DIP-40_W15.24mm_Socket

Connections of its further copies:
+5V: C30.1, C31.1, J23.2 (VCC), J24.4, R8.1, U19.10 (VCC), U19.30 (AVCC); also elsewhere on the board
/COPROC1_AREF: U19.32 (AREF); also elsewhere on the board
/COPROC1_PA0: U19.40 (PA0); also elsewhere on the board
/COPROC1_PA1: U19.39 (PA1); also elsewhere on the board
/COPROC1_PA2: U19.38 (PA2); also elsewhere on the board
/COPROC1_PA3: U19.37 (PA3); also elsewhere on the board
/COPROC1_PA4: U19.36 (PA4); also elsewhere on the board
/COPROC1_PA5: U19.35 (PA5); also elsewhere on the board
/COPROC1_PA6: U19.34 (PA6); also elsewhere on the board
/COPROC1_PA7: U19.33 (PA7); also elsewhere on the board
/COPROC1_PB0: U19.1 (PB0); also elsewhere on the board
/COPROC1_PB1: U19.2 (PB1); also elsewhere on the board
/COPROC1_PB2: U19.3 (PB2); also elsewhere on the board
/COPROC1_PB3: U19.4 (PB3); also elsewhere on the board
/COPROC1_PB4: U19.5 (PB4); also elsewhere on the board
/COPROC1_PB5: J23.4 (MOSI), U19.6 (PB5); also elsewhere on the board
/COPROC1_PB6: J23.1 (MISO), U19.7 (PB6); also elsewhere on the board
/COPROC1_PB7: J23.3 (SCK), U19.8 (PB7); also elsewhere on the board
/COPROC1_PC0: U19.22 (PC0); also elsewhere on the board
/COPROC1_PC1: U19.23 (PC1); also elsewhere on the board
/COPROC1_PC2: U19.24 (PC2); also elsewhere on the board
/COPROC1_PC3: U19.25 (PC3); also elsewhere on the board
/COPROC1_PC4: U19.26 (PC4); also elsewhere on the board
/COPROC1_PC5: U19.27 (PC5); also elsewhere on the board
/COPROC1_PC6: U19.28 (PC6); also elsewhere on the board
/COPROC1_PC7: U19.29 (PC7); also elsewhere on the board
/COPROC1_PD0: J24.3, U19.14 (PD0); also elsewhere on the board
/COPROC1_PD1: J24.2, U19.15 (PD1); also elsewhere on the board
/COPROC1_PD2: U19.16 (PD2); also elsewhere on the board
/COPROC1_PD3: U19.17 (PD3); also elsewhere on the board
/COPROC1_PD4: U19.18 (PD4); also elsewhere on the board
/COPROC1_PD5: U19.19 (PD5); also elsewhere on the board
/COPROC1_PD6: U19.20 (PD6); also elsewhere on the board
/COPROC1_PD7: U19.21 (PD7); also elsewhere on the board
/EXTCLK: U19.13 (XTAL1); also elsewhere on the board
/sheet847B5775/~PRG_RESET: C32.2, J22.3, J23.5 (~RST), R8.2
/sheet847B5775/~RESET: J22.2, U19.9 (~RESET)
/~MCU_RESET: J22.1; also elsewhere on the board
GND: C30.2, C31.2, J23.6 (GND), J24.5, J24.6, U19.11 (GND), U19.12 (XTAL2), U19.31 (GND); also elsewhere on the board
unnamed: C32.1, J24.1

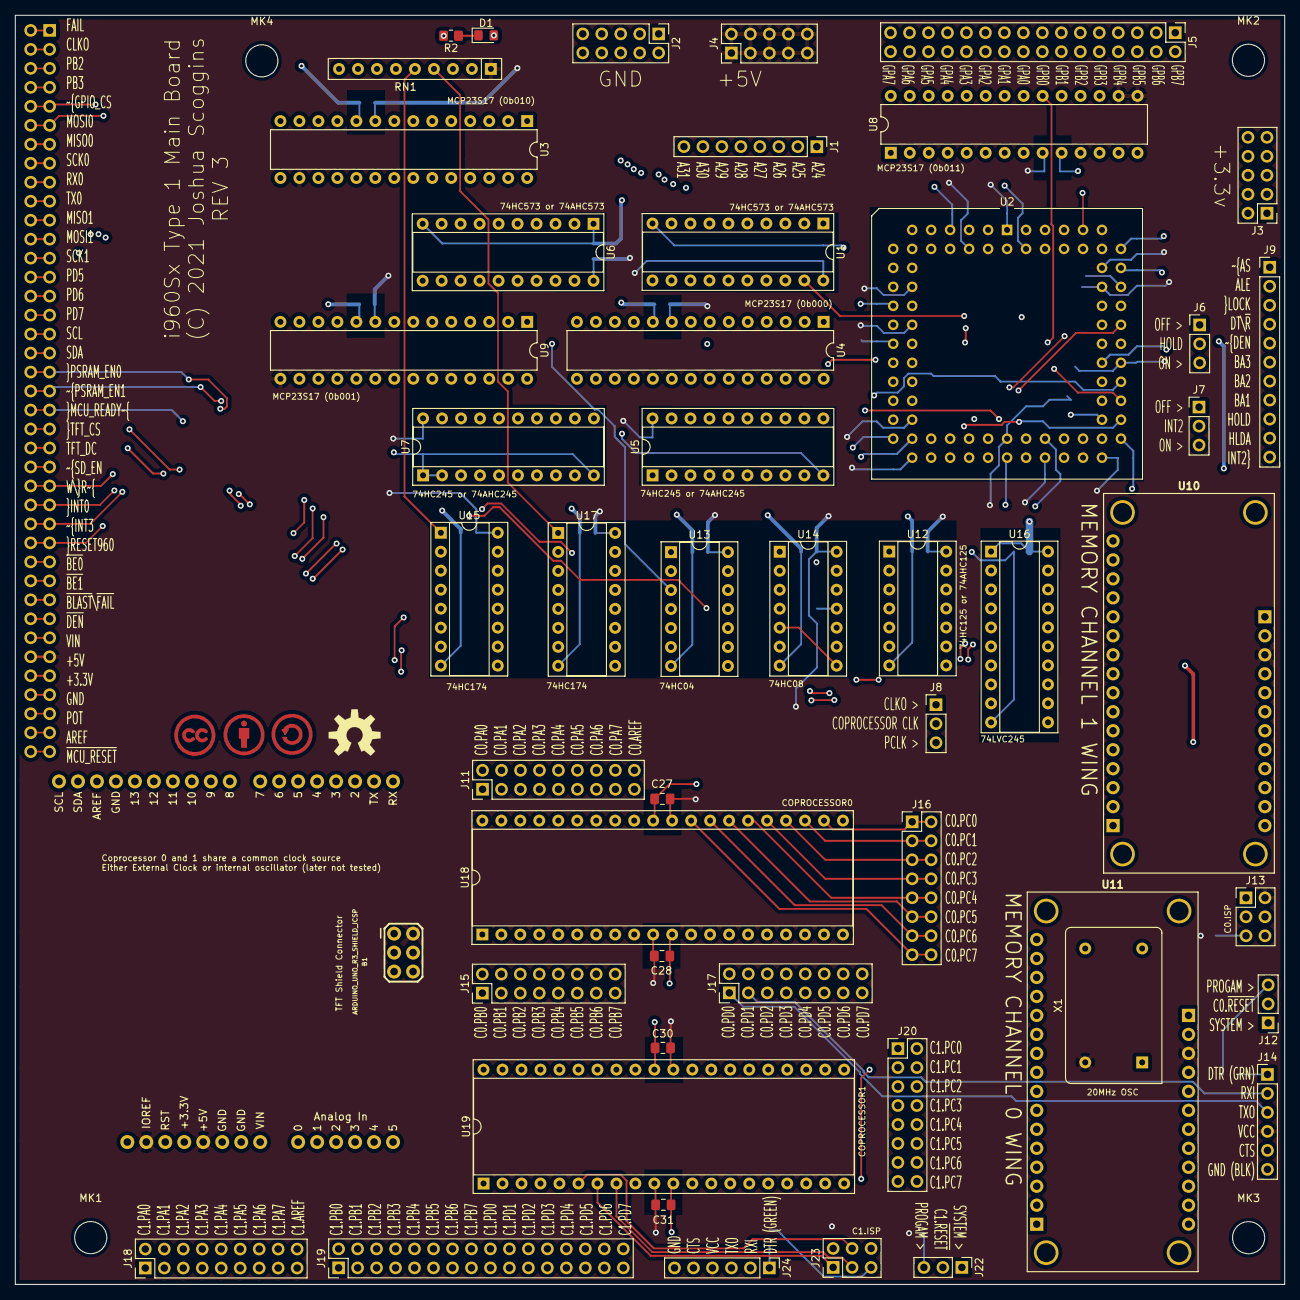
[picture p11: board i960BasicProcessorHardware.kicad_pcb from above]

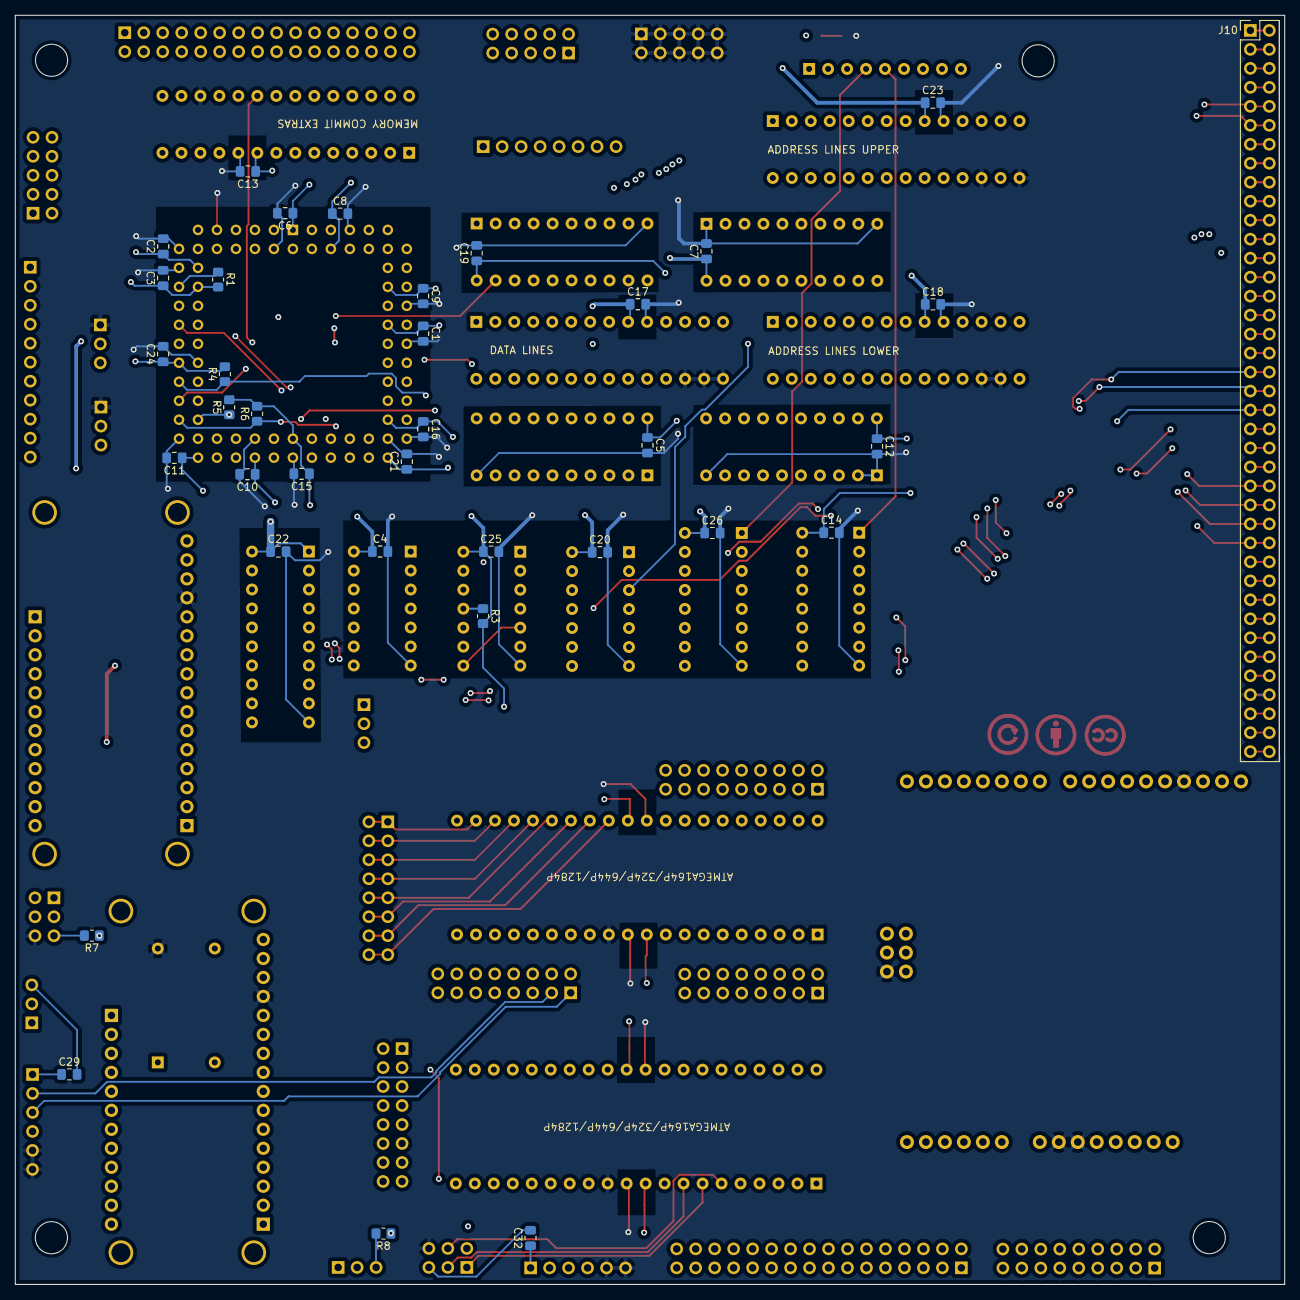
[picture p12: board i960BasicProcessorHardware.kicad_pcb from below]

Board: 4 copper layers, 169.9 x 169.8 mm, 90 parts (36 on the bottom side), 229 nets.

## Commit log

2021-10-16 Added a license (CC-BY-SA)
    Normally it would be BSD or zlib but in this case CC-BY-SA makes a lot
    more sense for hardware.
2021-10-16 move RESET960 and INT0 to the ioexpander
    PORTA on the fourth ioexpander is now fully populated.
    I am thinking of rearranging the pinout so that the analog pins are not
    in the middle of the analog port.
    [i960BasicProcessorHardware.sch]
2021-10-16 Move ~MCU_READY to PC4
    Added a pullup resistor to ~RESET960 to be on the safe side.
    PA1, PA2, and PA3 are now the free pins in PORTA
    [i960BasicProcessorHardware.sch]
2021-10-16 Updated pcb to reflect new design changes
    [i960BasicProcessorHardware.kicad_pcb, i960BasicProcessorHardware.sch]
2021-10-16 Update revision number
    [i960BasicProcessorHardware.kicad_pcb]
2021-10-16 Finish initial rev2
    [i960BasicProcessorHardware.kicad_pcb]
2021-10-16 move int0 back to the microcontroller and int1 to inta of 0b011 io expander
    [i960BasicProcessorHardware.kicad_pcb, i960BasicProcessorHardware.sch]
2021-10-16 Added an attiny85 for programming purposes
    It will be there solely for research purposes. It's clock will not be
    tied in at all, it is there for the purpose of trying stuff out.
    I also moved hold,hlda, and ~LOCK to the breakout header that ~AS, ALE,
    and others are attached to. I have plans to move ~INT3 to the
    microcontroller. I am also planning to expose the reset pin to the
    i960 itself so it can do a software reset.
    [i960BasicProcessorHardware.sch]
2021-10-16 part selection and fill removal
    [i960BasicProcessorHardware.kicad_pcb, i960BasicProcessorHardware.sch]
2021-10-16 Finished adding the attiny85
    [i960BasicProcessorHardware.kicad_pcb, i960BasicProcessorHardware.sch]
2021-10-16 moved int2 and int3 to the signal breakout
    I did not directly connect ~int3 to the microcontroller setup. I want to
    leave it free for any future design ideas. Clock synchronization is
    important but not impossible to work around.
    I am still wondering if I should break the 8 most significant bits of
    the address out to a separate header for future expansion effort.
    [i960BasicProcessorHardware.kicad_pcb, i960BasicProcessorHardware.sch]
2021-10-16 Decided to break the highest 8 bits of the address out to a separate header.
    I've done it before when I made the processor card interface. I can
    position it fairly close without fear of signal degredation
    [i960BasicProcessorHardware.sch]
2021-10-16 Rearrange some of the board and move the interrupt pull ups to individual resistors
    [i960BasicProcessorHardware.kicad_pcb, i960BasicProcessorHardware.sch]
2021-10-16 Upper 8 breakout successfully routed in
    [i960BasicProcessorHardware.kicad_pcb]
2021-10-16 Separate ~RESET960's pullup to a separate resistor
    I have plenty of space underneath the plcc socket for resistors
    [i960BasicProcessorHardware.sch]
2021-10-16 move ~RESET960 back to the primary chipset
    also move ~INT3 to it as well. I want two different interrupt pins
    accessible to the primary chipset. I have made the fourth ioexpander
    completely exposed to the i960.
    [i960BasicProcessorHardware.kicad_pcb, i960BasicProcessorHardware.sch]
2021-10-16 Wireup the fourth gpio expander
    [i960BasicProcessorHardware.kicad_pcb, i960BasicProcessorHardware.sch]
2021-10-16 Update labels and delete bad trace
    [i960BasicProcessorHardware.kicad_pcb]
2021-10-16 Drop the attiny85 because I'm going to put several extra attiny861s in its place
    [i960BasicProcessorHardware.sch]
2021-10-16 Drop the attiny85
    I am going to place two 861s instead tied to the same 20mhz clock
    I am also considering adding a dip40 socket also tied to the same
    20mhz clock
    [i960BasicProcessorHardware.kicad_pcb, i960BasicProcessorHardware.sch]
2021-10-16 Move the attiny861 schematic to a sub schematic
    I am planning to have multiple of them
    [Attiny861COPROC.sch, i960BasicProcessorHardware.sch]
2021-10-16 Breakout other lines
    [Attiny861COPROC.sch]
2021-10-16 fixup int0 for the attiny861 to be pb6
    Add a second attiny861
    [Attiny861COPROC.sch, i960BasicProcessorHardware.sch]
2021-10-16 We always have access to the 861s
    [Attiny861COPROC.sch, i960BasicProcessorHardware.kicad_pcb, i960BasicProcessorHardware.sch]
2021-10-16 pull in a 1284p socket setup
    [Attiny861COPROC.sch, i960BasicProcessorHardware.kicad_pcb, i960BasicProcessorHardware.sch]
2021-10-16 Drop the attiny861s and add the 1284p based coprocessor in its place
    [ATMEGAx4SeriesCoprocessor.sch, i960BasicProcessorHardware.sch]
2021-10-16 ATMEGAx4 coprocessor is basically setup
    [ATMEGAx4SeriesCoprocessor.sch, i960BasicProcessorHardware.sch]
2021-10-16 Partially pinout the extra x4 hardware
    [ATMEGAx4SeriesCoprocessor.sch, i960BasicProcessorHardware.sch]
2021-10-16 start moving the 74lvc245 to free up some space
    [i960BasicProcessorHardware.kicad_pcb, i960BasicProcessorHardware.sch]
2021-10-16 Add an onboard oscillator when it is necessary to program the secondary processor
    [i960BasicProcessorHardware.kicad_pcb, i960BasicProcessorHardware.sch]
2021-10-16 Drop the extra breakout for spi
    [i960BasicProcessorHardware.sch]
2021-10-16 Move the coprocessor clock source selector to the main page
    [ATMEGAx4SeriesCoprocessor.sch, i960BasicProcessorHardware.kicad_pcb, i960BasicProcessorHardware.sch]
2021-10-17 breakout all of the coprocessor0 pins to separate headers
    Bundle the AREF pin with PORTA
    [i960BasicProcessorHardware.kicad_pcb, i960BasicProcessorHardware.sch]
2021-10-17 Double headers for each co processor
    Added a second coprocessor
    [ATMEGAx4SeriesCoprocessor.sch, i960BasicProcessorHardware.kicad_pcb, i960BasicProcessorHardware.sch]
2021-10-17 Keep futzing with the design
    Added a missing +5v power source to the x4 coprocessor schematic
    [ATMEGAx4SeriesCoprocessor.sch, i960BasicProcessorHardware.kicad_pcb, i960BasicProcessorHardware.sch]
2021-10-17 Rudimentary layout
    [i960BasicProcessorHardware.kicad_pcb, i960BasicProcessorHardware.sch]
2021-10-17 Get the two co processors laid out properly and start wiring it up
    [ATMEGAx4SeriesCoprocessor.sch, i960BasicProcessorHardware.kicad_pcb, i960BasicProcessorHardware.sch]
2021-10-17 Finish cleaning up rev3 for now the layout is complete
    [ATMEGAx4SeriesCoprocessor.sch, i960BasicProcessorHardware.kicad_pcb, i960BasicProcessorHardware.sch]
2021-10-17 First version of rev3 done
    [i960BasicProcessorHardware.kicad_pcb]
2021-10-17 Finished labeling everything
    [i960BasicProcessorHardware.kicad_pcb]
2021-10-17 Fix placement of info tag
    [i960BasicProcessorHardware.kicad_pcb]
2021-10-17 Added a pullup resistor for each programming reset line
    [ATMEGAx4SeriesCoprocessor.sch]
2021-10-17 Installed the two missing pullup resistors
    [i960BasicProcessorHardware.kicad_pcb]
2021-10-17 Text modifications and license additions
    [i960BasicProcessorHardware.kicad_pcb]
2021-10-17 Fix names
    [i960BasicProcessorHardware.kicad_pcb]
2021-10-17 Get more space
    [ATMEGAx4SeriesCoprocessor.sch, i960BasicProcessorHardware.sch]

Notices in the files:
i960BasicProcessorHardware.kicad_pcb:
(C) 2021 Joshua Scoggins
